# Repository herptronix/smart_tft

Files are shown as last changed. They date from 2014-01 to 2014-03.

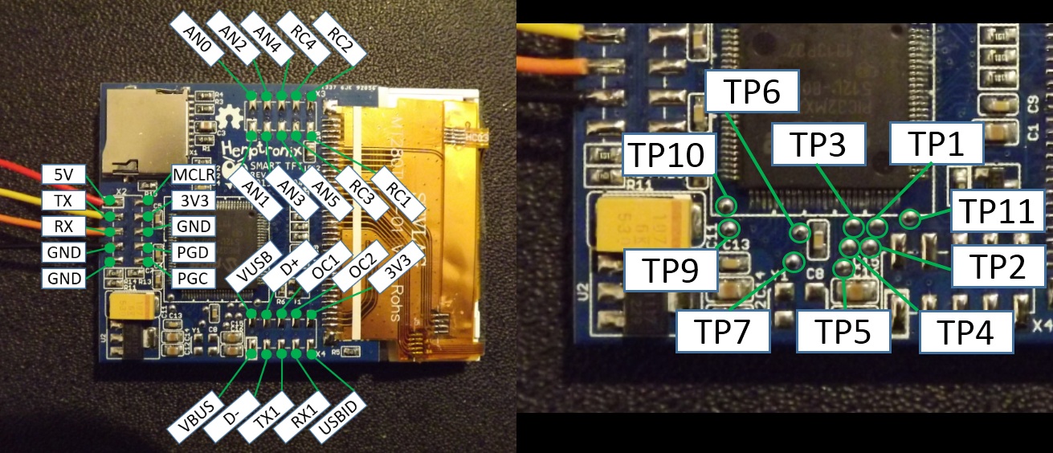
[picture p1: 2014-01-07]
documentation/pin_description.jpg

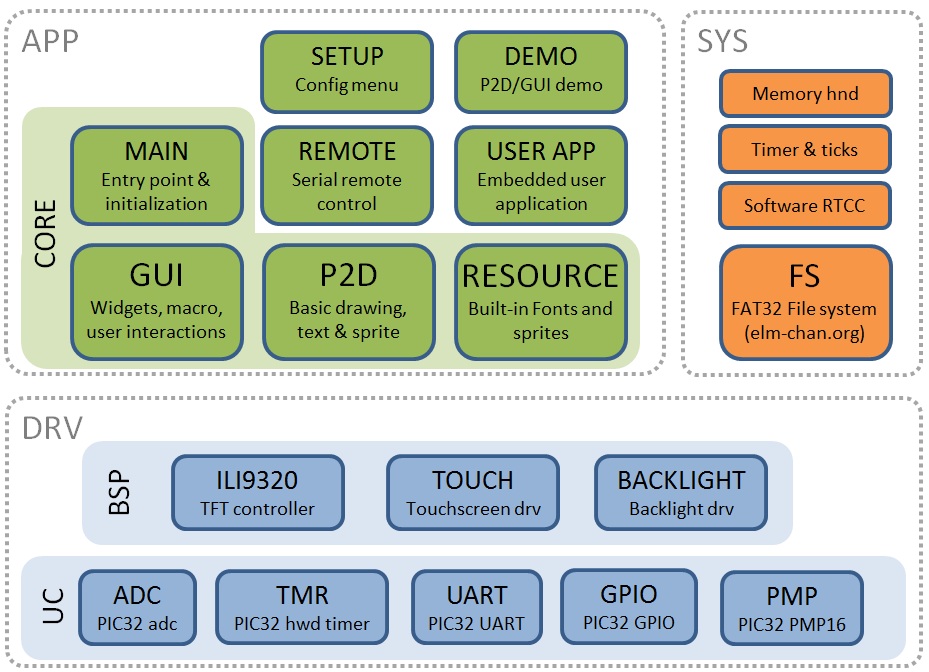
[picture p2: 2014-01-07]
documentation/software_arch.jpg

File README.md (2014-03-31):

Smart TFT module
================

Open source (hardware & software) smart TFT module, based on:
 - Microchip PIC32MX795F512L microcontroller
 - 3.2" TFT 320x240, ILI9320/9325 controller
 - optional µSD card, for extra storage

This module has three operational modes:
 - slave: an other microcontroller sends commands to the TFT through UART (1M bauds, 8N1)
 - embedded app: the user includes its application directly into the PIC32
 - setup: setup menu, for touchscreen callibration, gamma adjustement & software demo; enter this mode by keeping the touchscreen pressed while powering on the 5V PSU.

Small video: https://www.youtube.com/watch?v=Nt97tPhJtdA
Some explanations (french only): http://herptronix.blogspot.fr/

## Pins & wirepads description ##
pin_desription

## Software modules ##
software_arch

## Screenshots ##
screenshots

## Pickit3 ##
pickit

Status
======

Maintained

 - 2014/03/31 Add sprite & font converters (sources & win32 exe)
 - 2014/02/27 Add display orientation support (limited to BSP) & Minor bug fixes
 - 2014/02/01 Minor bug fixes (p2d_font.c / touchCalib.c / gui_w_usr_entry.c)
 - 2014/01/15 Add a quick & dirty (... and not yet completed) dev. guide
 - 2014/01/09 Add a serial remote example
 - 2013/12/29 Rev. A (improved P2D/GUI, FAT-FS support, setup menu, serial comm support)
 - 2013/08/11 First GUI version (not on git)
 - 2013/07/13 First P2D version (not on git)

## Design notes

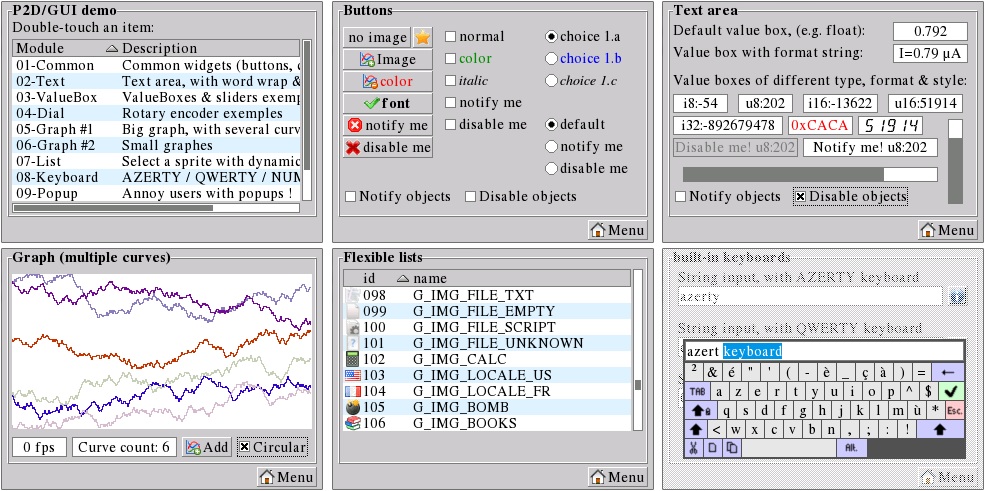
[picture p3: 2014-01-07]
documentation/screenshots.jpg

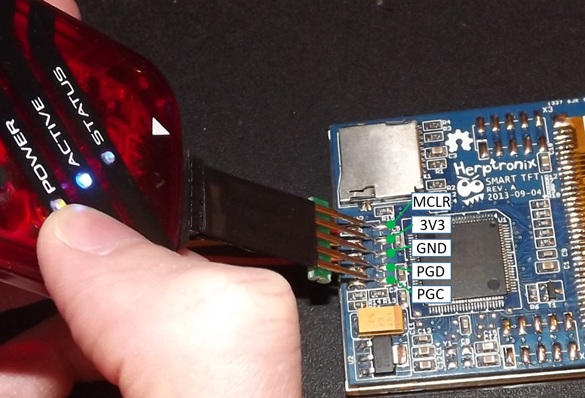
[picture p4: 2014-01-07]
documentation/pickit.jpg

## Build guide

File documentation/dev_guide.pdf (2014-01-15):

Herptronix

Smart display dev. guide

DRAFT / UNCOMPLETE

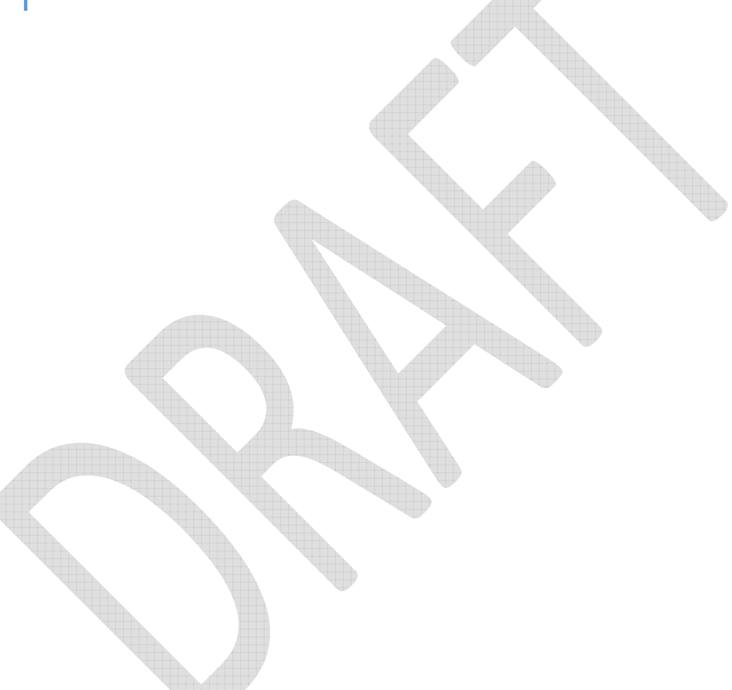
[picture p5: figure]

Developer Guide | 1 / 68

### 1. Summary

Developer Guide | 2 / 68

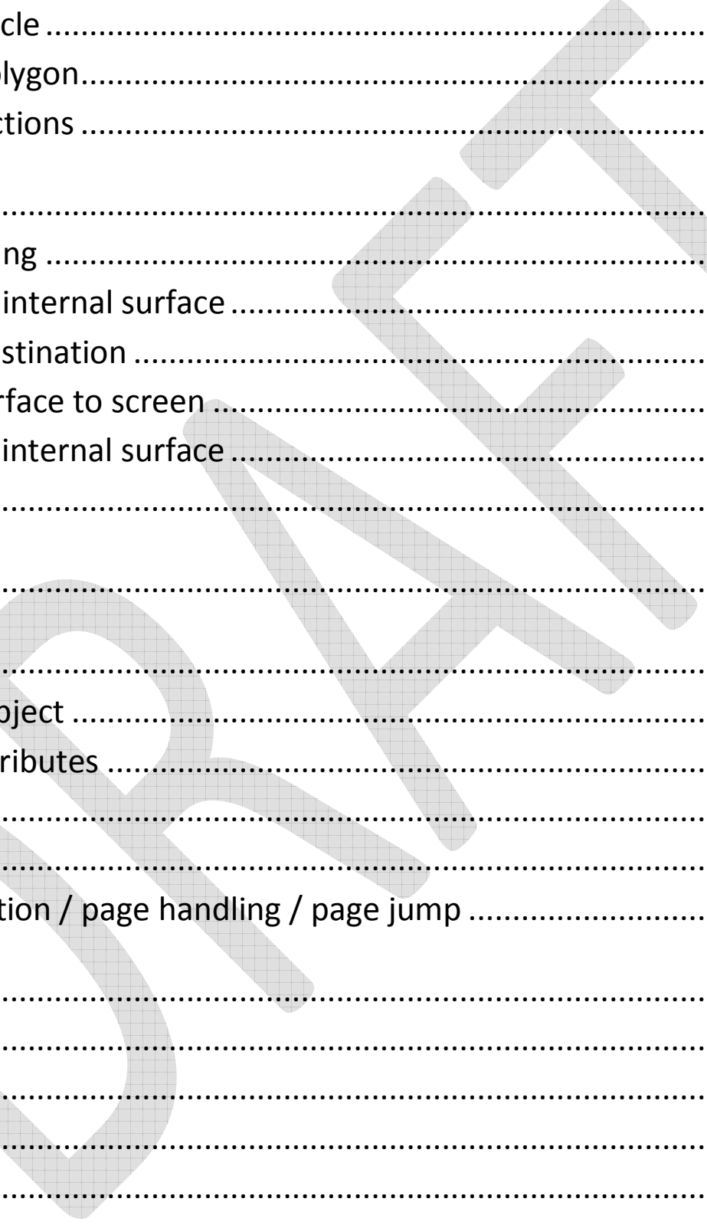
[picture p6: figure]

Developer Guide | 3 / 68

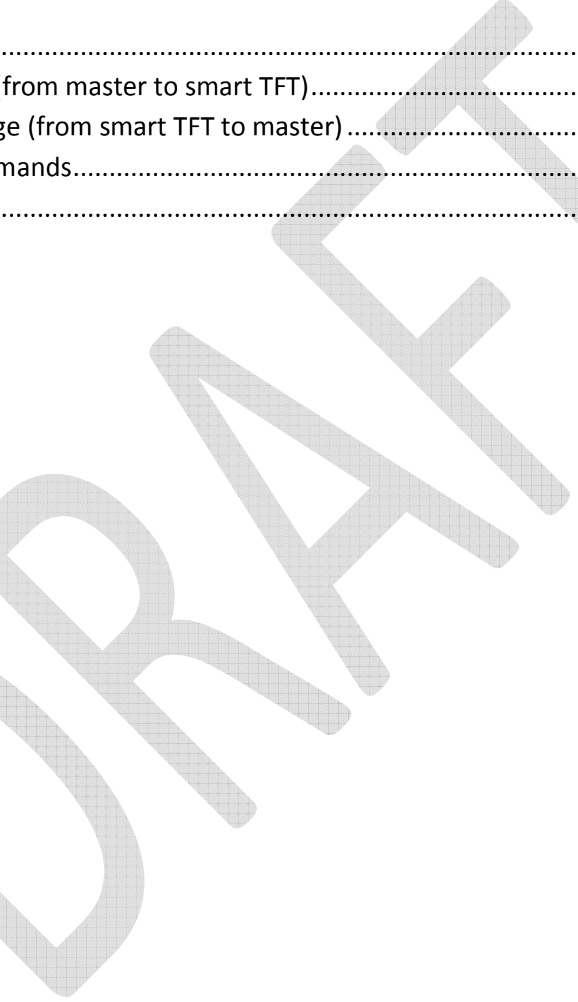
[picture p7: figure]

Developer Guide | 4 / 68

### 2. Licensing

Software of this project is under GPL3 license:

This program is free software: you can redistribute it and/or modify it under the terms of the GNU General Public License as published by the Free Software Foundation, either version 3 of the License, or (at your option) any later version.

This program is distributed in the hope that it will be useful, but WITHOUT ANY WARRANTY; without even the implied warranty of MERCHANTABILITY or FITNESS FOR A PARTICULAR PURPOSE. See the GNU General Public License for more details.

You should have received a copy of the GNU General Public License along with this program. If not, see

http://www.gnu.org/licenses/.

### 3. Overview

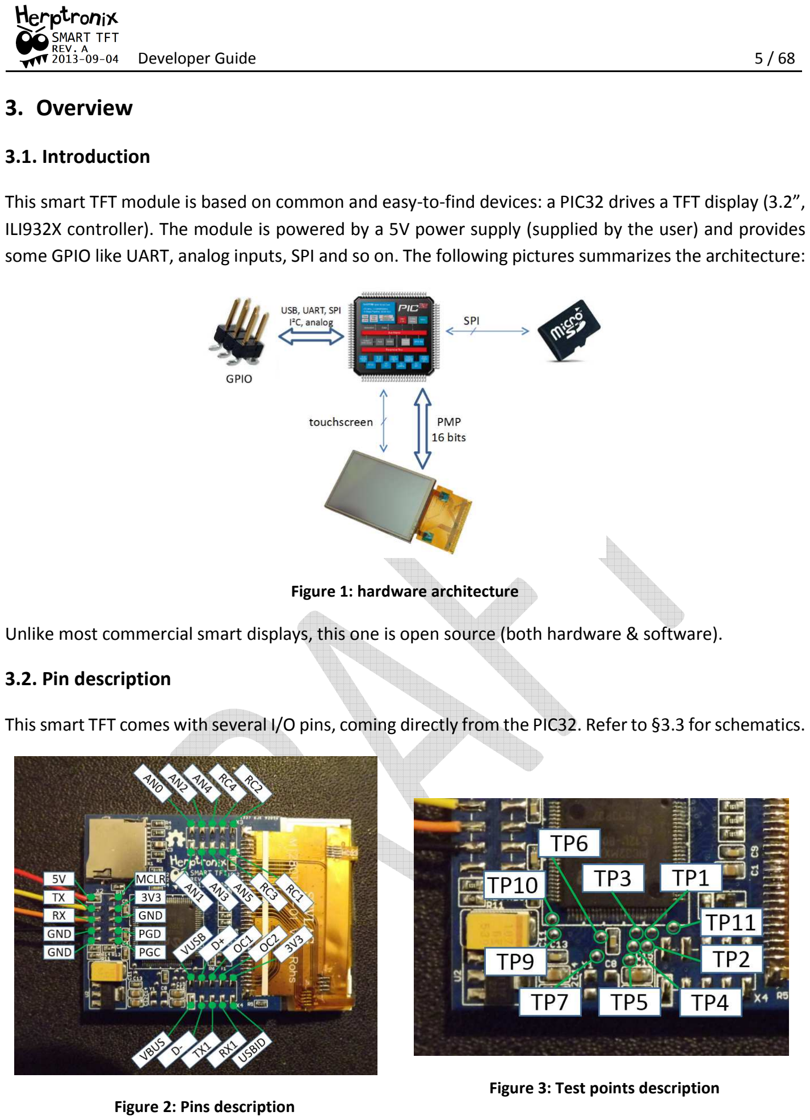
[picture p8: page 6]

Developer Guide | 5 / 68

### 3.1. Introduction

This smart TFT module is based on common and easy-to-find devices: a PIC32 drives a TFT display (3.2”, ILI932X controller). The module is powered by a 5V power supply (supplied by the user) and provides some GPIO like UART, analog inputs, SPI and so on. The following pictures summarizes the architecture:

Figure 1: hardware architecture

Unlike most commercial smart displays, this one is open source (both hardware & software).

### 3.2. Pin description

This smart TFT comes with several I/O pins, coming directly from the PIC32. Refer to §3.3 for schematics.

Figure 2: Pins description

Figure 3: Test points description

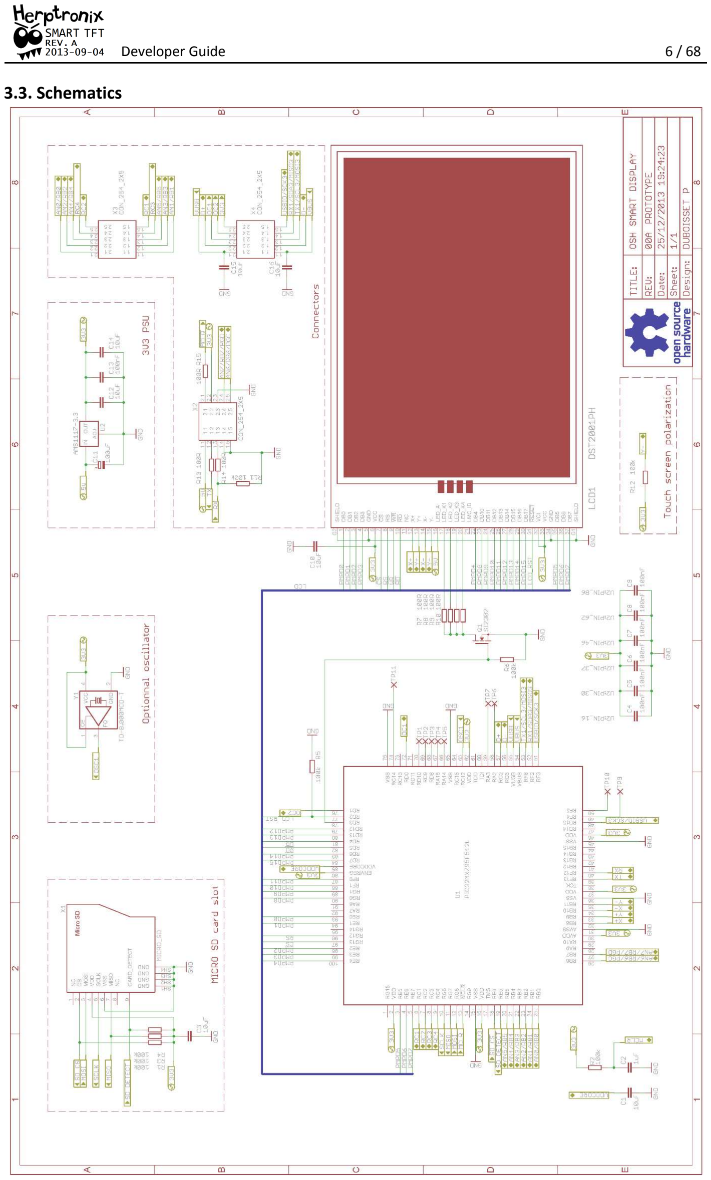
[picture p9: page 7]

Developer Guide | 6 / 68

### 3.3. Schematics

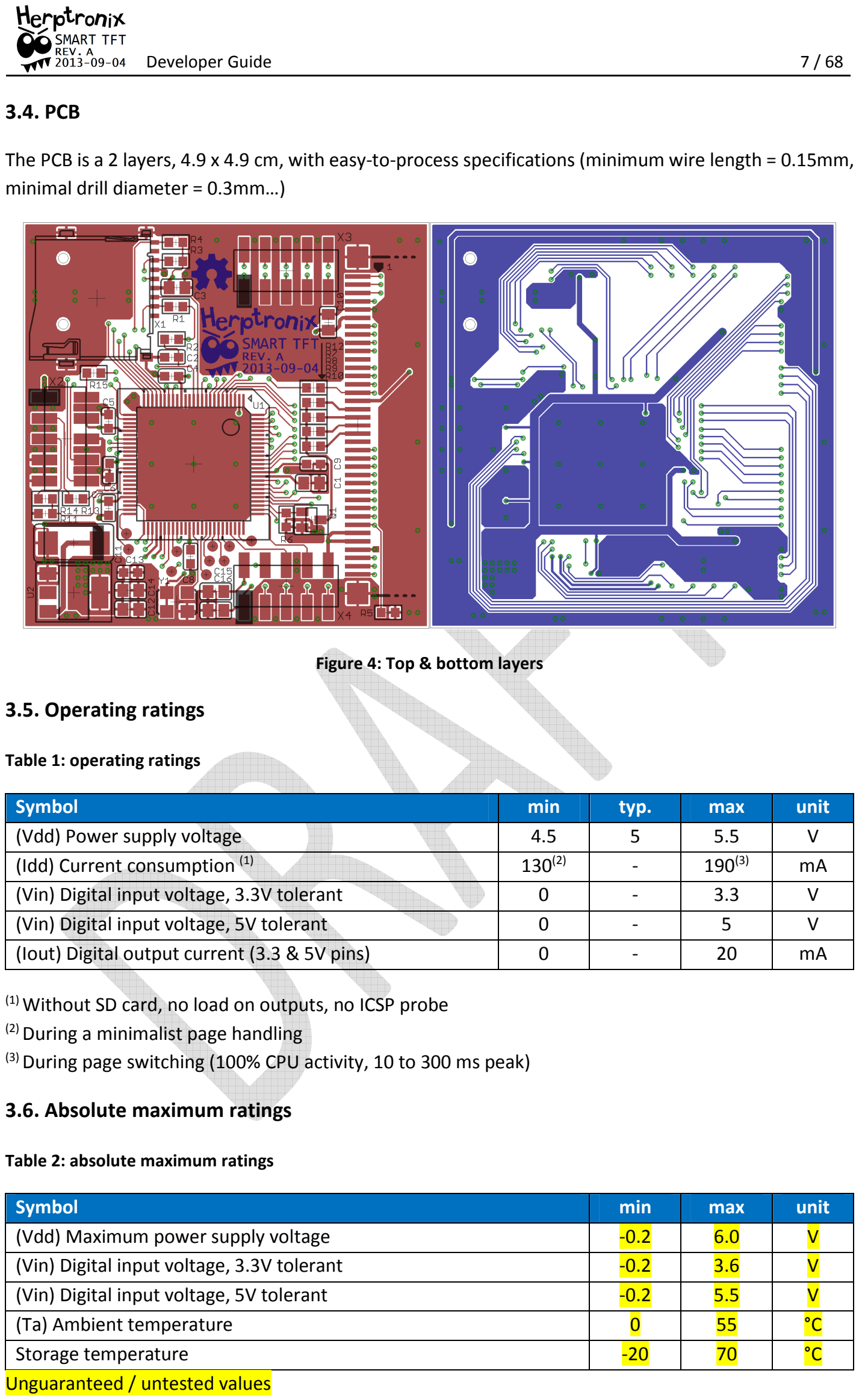
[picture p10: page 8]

Developer Guide | 7 / 68

### 3.4. PCB

The PCB is a 2 layers, 4.9 x 4.9 cm, with easy-to-process specifications (minimum wire length = 0.15mm, minimal drill diameter = 0.3mm…)

Figure 4: Top & bottom layers

### 3.5. Operating ratings

Table 1: operating ratings

Symbol | min | typ. | max | unit
(Vdd) Power supply voltage | 4.5 | 5 | 5.5 | V
(Idd) Current consumption ⁽¹⁾ | 130 (2) | - | 190⁽³⁾ | mA
(Vin) Digital input voltage, 3.3V tolerant | 0 | - | 3.3 | V
(Vin) Digital input voltage, 5V tolerant | 0 | - | 5 | V
(Iout) Digital output current (3.3 & 5V pins) | 0 | - | 20 | mA
(1) Without SD card, no load on outputs, no ICSP probe
(2) During a minimalist page handling
(3) During page switching (100% CPU activity, 10 to 300 ms peak)

### 3.6. Absolute maximum ratings

Table 2: absolute maximum ratings

Symbol | min | max | unit
(Vdd) Maximum power supply voltage | -0.2 | 6.0 | V
(Vin) Digital input voltage, 3.3V tolerant | -0.2 | 3.6 | V
(Vin) Digital input voltage, 5V tolerant | -0.2 | 5.5 | V
(Ta) Ambient temperature | 0 | 55 | °C
Storage temperature | -20 | 70 | °C
Unguaranteed / untested values

Developer Guide | 8 / 68

### 3.7. Mode of operation

This smart TFT has 2 different operational modes, selected at compilation time:
- Slave mode
- Embedded application mode
Another mode (setup mode) is always included, which provides a software demonstration, touchscreen configuration and gamma adjustment.

### 3.7.1. Slave (default)

In slave mode (which is the default mode), the smart TFT executes commands sent by a master (e.g. another MCU) through the UART. The firmware of the smart TFT does not require any modification, but the master shall integrate some additional source files for driving it. These source files are provided as an example, and should be re-written in a more efficient way.

For using the slave mode, the smart TFT shall be wired to a remote system through 4 wires:

- 5VIN: 5V power supply (see Table 1: operating ratings for current consumption)
- GND: power supply ground
- TX: Transmitted data (from the smart TFT to the master). This pin shall be connected to the RX of the master
- RX: Received data (from the master to the smart TFT). This pin shall be connected to the TX of the master

Default configuration is set to 1M bauds, 8N1. UART speed can be changed by modifying the UART_SPEED definition in <src/app/serial_remote/serial_common.h> file.

### 3.7.2. Embedded application

In this mode, the user application is integrated into the firmware of the smart TFT; user will have to modify the source code and upload its custom firmware into the smart TFT with an ICSP probe (e.g. a PICKIT 3). Paragraphs below describe a typical procedure for enabling this mode.

The smart TFT does not include a bootloader yet. An ICSP probe is required to upgrade the firmware

3.7.2.1.Get the MPLAB X project

The distributed MPLAB X project has been released using the following tools:
- MPLAB X version 1.90
- C32 compiler version 2.02, using –O3 optimizations (if you do not have the license, the free version provides these optimizations during 60 days). Compilation with another compiler (e.g. XC32) has not been tested.

3.7.2.2.Configure the ICSP probe

Just ensure that the ICSP probe is powered by the smart TFT (here, a PICKIT3 cannot power the smart TFT; it would damage it):

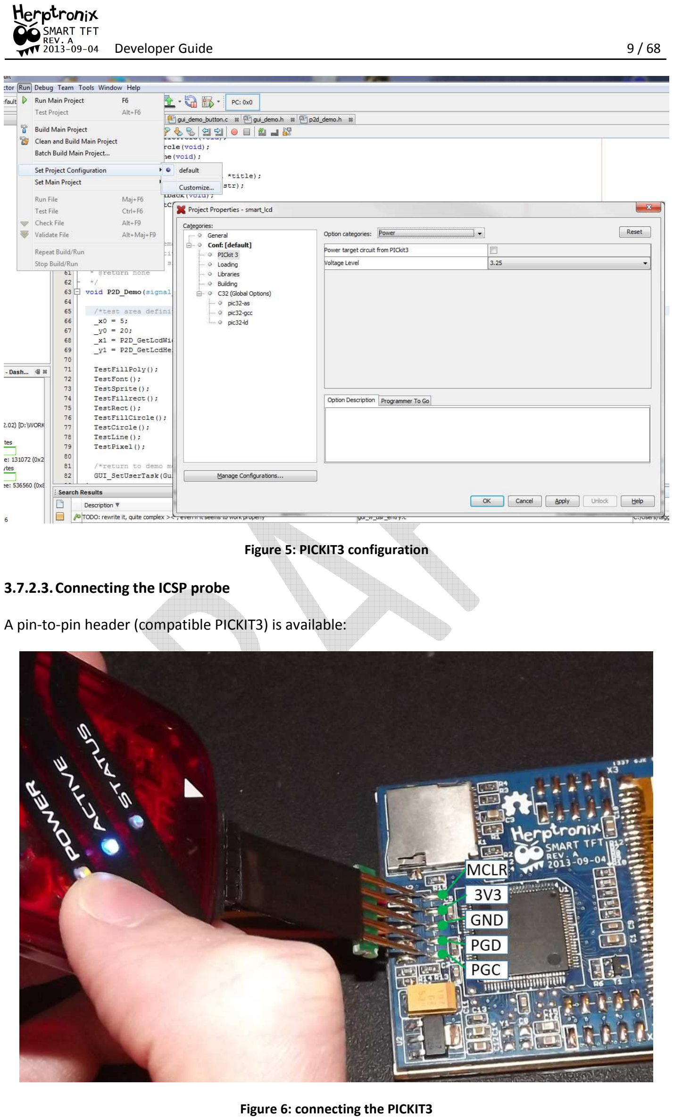
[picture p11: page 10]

Developer Guide | 9 / 68

Figure 5: PICKIT3 configuration

3.7.2.3.Connecting the ICSP probe

A pin-to-pin header (compatible PICKIT3) is available:

Figure 6: connecting the PICKIT3

Developer Guide | 10 / 68

3.7.2.4.Define the embedded app mode

Open the <src/main.h> header and comment the SMART_TFT_SLAVE_MODE symbol:

3.7.2.5.Include your app

You can add your program in the UserTask() function, located in <src/app/usr/usr_main.c> file. The firmware of the smart TFT will call this function at each software cycle.
A basic embedded application is included in source code (comes as an example).

Due to the absence of RTOS, the embedded application shall manually yield the CPU (i.e. do not use infinite loop).

### 3.7.3. Setup

This mode allows configuring the touchscreen and running a demonstration. This mode is launched following the steps below:
- With the smart TFT powered OFF, press the touch screen
- By keeping the touch screen pressed, power ON the smart TFT
The setup screen appears:

After 3 seconds of inactivity from the touchscreen, the smart TFT will enter the highlighted item.

3.7.3.1.Touchscreen calibration

Touchscreen calibration is based on a 2 points algorithm

Parameters for touchscreen calibration are stored on the µSD card (/TOUCHSCR.CFG file); if the µSD card is not inserted, touchscreen will be calibrated with internal default parameters (i.e. without the TOUCHSCR.CFG file, the touchscreen may be “reversed”).

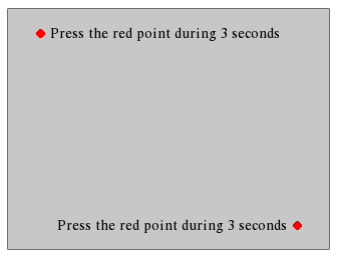
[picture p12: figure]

Developer Guide | 11 / 68

3.7.3.2.Gamma adjustment

Parameters for gamma adjustment are stored on the µSD card (/GAMMA.CFG file); if the µSD card is not inserted, gamma will be calibrated with internal default parameters

Report to the TFT controller documentation for the description of gamma registers

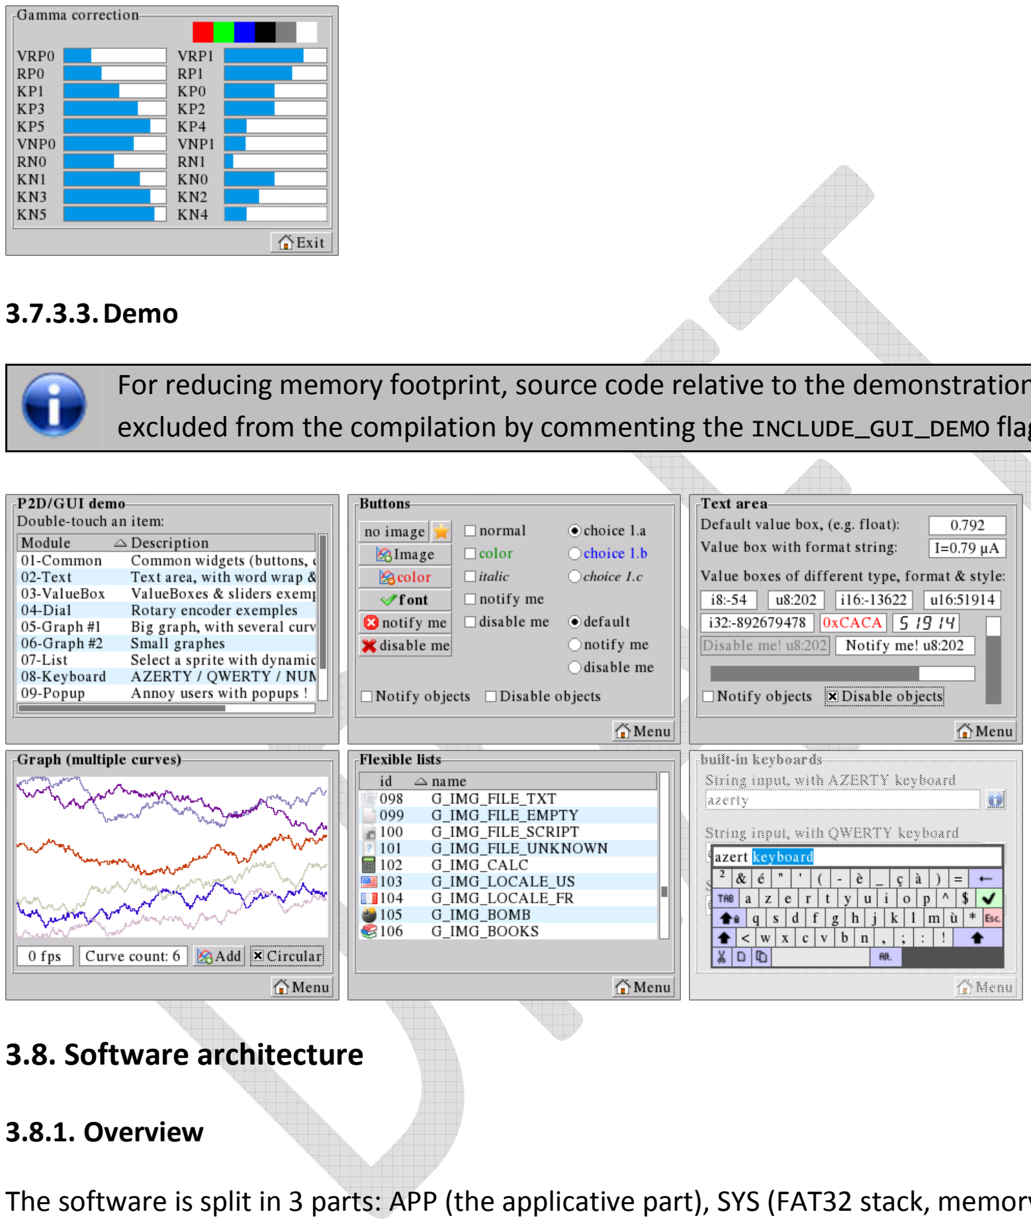
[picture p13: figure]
3.7.3.3.Demo; 3.8. Software architecture; 3.8.1. Overview

For reducing memory footprint, source code relative to the demonstration can be easily excluded from the compilation by commenting the INCLUDE_GUI_DEMO flag in <main.h>

The software is split in 3 parts: APP (the applicative part), SYS (FAT32 stack, memory allocator, etc…) and DRV (peripherals & microcontroller drivers).

The Figure 7: software architecture describes the software architecture:

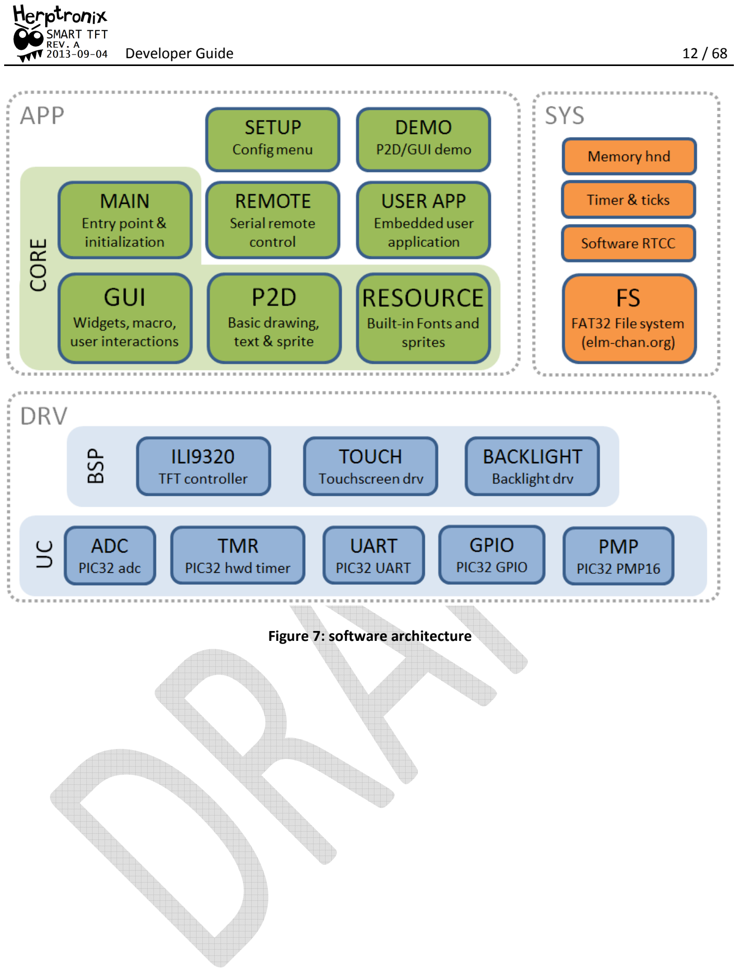
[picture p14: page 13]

Developer Guide | 12 / 68

Figure 7: software architecture

Developer Guide | 13 / 68

### 3.8.2. Files description

The table above lists source code files constituting this project.

Table 3: Files description

File (.c) | Description
main | The main function; includes initialization and main loop
app\gui\macro\file_browser\gui_m_file_browser | Built-in file browser (µSD file browser)
app\gui\macro\keyboard\ gui_m_keyboard | Built-in keyboard (AZERTY / QWERTY & NUM, with insert / copy-paste features)
app\gui\macro\keyboard\ gui_w_key | Small widget for the built-in keyboard
app\gui\macro\keyboard\ keymap | Keyboards mappings (describes keys for AZERTY / QWERTY & NUM configuration)
app\gui\macro\list\ gui_m_list | Lists builder; create flexible lists, the easy way.
app\gui\macro\popup\ gui_m_popup | Built-in popups
app\gui\widgets\gui_w_button | Standard buttons
app\gui\widgets\gui_w_checkBox | Standard check boxes
app\gui\widgets\gui_w_frame | Frames (a text plus a rectangle)
app\gui\widgets\gui_w_graph | Graphs (normal & scrolled)
app\gui\widgets\gui_w_led | LED (red or green, according to their relative status)
app\gui\widgets\gui_w_list | Flexible lists implementation; use functions provided by gui_m_list
app\gui\widgets\gui_w_radio | Standard radios
app\gui\widgets\gui_w_rot_button | Rotary encoder
app\gui\widgets\gui_w_rot_value | Special value box, for rotary encoder
app\gui\widgets\gui_w_scroller | Standard scroll bar
app\gui\widgets\gui_w_slider | Standard slider
app\gui\widgets\gui_w_tab | Tabs (deprecated)
app\gui\widgets\gui_w_text | Text area (supports alignment & line feed)
app\gui\widgets\gui_w_usr_entry | User entry bar; allow string edition
app\gui\widgets\gui_w_valueBox | Value boxes; display formatted values

Developer Guide | 14 / 68
app\gui\gui_debug | GUI debug utils (memory usage)
app\gui\gui_graphics | GUI graphic wrapper; handle fonts & sprites through #id
app\gui\gui_obj | GUI generic object implementation + GUI task
app\gui\gui_utils | GUI utility
app\gui_demo\gui_demo | Main menu of GUI demo
app\gui_demo\gui_demo_button | generic widgets demo (buttons, radios, checkboxes)
app\gui_demo\gui_demo_file_browser | file browser demo
app\gui_demo\gui_demo_graph1 | graph demo #1 (big graph with multiple curves)
app\gui_demo\gui_demo_graph2 | graph demo #2 (small graphs & grid)
app\gui_demo\gui_demo_keyboard | keyboard demo
app\gui_demo\gui_demo_list | flexible lists demo
app\gui_demo\gui_demo_popup | popup demo
app\gui_demo\gui_demo_rbutton | rotary encoder demo
app\gui_demo\gui_demo_sd | SD card example
app\gui_demo\gui_demo_text | text area demo
app\gui_demo\gui_demo_valuebox | value boxes demo
app\p2d\p2d_base | Basic 2D functions (pixel, rectangle, …)
app\p2d\p2d_buffer | Memory buffer (deprecated)
app\p2d\p2d_clip | Clipping
app\p2d\p2d_colors | Color conversion (RGB888 <-> RGB565, alpha, B&W…)
app\p2d\p2d_font | Text rendering
app\p2d\p2d_geo_circle | Circle & filled circle
app\p2d\p2d_geo_line | Lines
app\p2d\p2d_geo_poly | Polygon & filled polygon, plus polygon-oriented functions
app\p2d\p2d_internal | Functions dispatching (to TFT or to memory)
app\p2d\p2d_lut | Color look-up tables
app\p2d\p2d_math | Some math functions
app\p2d\p2d_sprite | Sprite rendering (only 8BPP)

Developer Guide | 15 / 68
app\p2d\p2d_utils | Some utils (distance calculation, etc…)
app\resources\FontDigit_4bpp | Font digit (7 segments style)
app\resources\FontSerif_4bpp_b | Font free serif, bold; comes with many heights.
app\resources\FontSerif_4bpp_i | Font free serif, italic; comes with many heights.
app\resources\FontSerif_4bpp_n | Font free serif, normal; comes with many heights.
app\resources\FontSymbol | Some symbol used by the built-in keyboard
app\resources\sprite00 | Sprite pack #00 (16x16)
app\resources\sprite01 | Sprite pack #01 (16x16)
app\resources\sprite02 | Sprite pack #02 (16x16)
app\resources\sprite03 | Sprite pack #03 (16x16)
app\resources\sprite04 | Sprite pack #04 (32x32)
app\serial_remote\opList | List of operators (~ link with P2D/GUI) handled by the serial remote
app\serial_remote\r_gui | GUI serialized functions
app\serial_remote\r_mem | Memory serialized functions
app\serial_remote\r_p2d | P2D serialized functions
app\serial_remote\serial_remote | Serial remote task & FSM
app\serial_remote\serial_rx | Functions for message reception
app\serial_remote\serial_tx | Functions for message emission
app\serial_remote\ssm | Serialized shared memory
app\setup\gamma | Gamma adjustment
app\setup\setup | Setup menu
app\setup\touchCalib | Touchscreen calibration
app\user_app\usr_main | User application (disabled by default)
drv\bsp\backlight | Backlight driver (dummy for now)
drv\bsp\ILI9320 | TFT controller driver
drv\bsp\touchscreen | Touchscreen driver
drv\uc\adc | PIC32 ADC driver
drv\uc\configuration_bits | PIC32 fuses

Developer Guide | 16 / 68
drv\uc\gpio | PIC32 GPIO driver
drv\uc\hw_config | Hardware constants (e.g. clock frequency)
drv\uc\pmp | PIC32 parallel master port driver (16 bits mode)
drv\uc\sem | Atomic write macro (quick & dirty spinlock for interrupts)
drv\uc\tmr | PIC32 timers driver
drv\uc\uart | PIC32 UART driver
drv\uc\uc | PIC32 core utils (e.g. sleep mode)
sys\file_system\diskio | FAT-FS part (see http://elm-chan.org/fsw/ff/00index_e.html)
sys\file_system\ff | FAT-FS part (see http://elm-chan.org/fsw/ff/00index_e.html)
sys\file_system\ffconf | FAT-FS part (see http://elm-chan.org/fsw/ff/00index_e.html)
sys\file_system\integer | FAT-FS part (see http://elm-chan.org/fsw/ff/00index_e.html)
sys\file_system\mmcPIC32 | PIC32 specific for FAT-FS
sys\delay | Delay functions
sys\rtc | Software RTCC (needed by FAT-FS)
sys\salloc | Custom memory allocator (used by GUI)
sys\ticks | Software clock
sys\timer | Software timers

Developer Guide | 17 / 68

### 4. Built-in resources

The firmware includes some built-in graphical resources (images and fonts). These resources are listed in the tables below.

### 4.1. Images

The tables below list built-in images and their available CLUTs. Built-in images come from the open icon library project (http://openiconlibrary.sourceforge.net/)

Due to bandwidth limitations, P2D & GUI do not handle images which are located on the micro SD card.

Table 4: available CLUTs

CLUT symbol | Description
G_LUT_NORMAL | This CLUT is the ‘default’ one; by using this CLUT, the image will be displayed as it appears in Table 5 & Table 6
G_LUT_DISABLED | By using this CLUT, the image will be displayed in black & white; due to memory limitations, this CLUT is not available for all images.

Table 5: built-in 16x16 images

defined symbol (see src/app/resources.h) | Available CLUTs
G_IMG_OK | G_LUT_NORMAL, G_LUT_DISABLED
G_IMG_NO | G_LUT_NORMAL, G_LUT_DISABLED
G_IMG_ADD | G_LUT_NORMAL, G_LUT_DISABLED
G_IMG_REMOVE | G_LUT_NORMAL, G_LUT_DISABLED
G_IMG_LEFT_ARROW | G_LUT_NORMAL, G_LUT_DISABLED
G_IMG_LEFT_D_ARROW | G_LUT_NORMAL, G_LUT_DISABLED
G_IMG_DOWN_ARROW | G_LUT_NORMAL, G_LUT_DISABLED
G_IMG_DOWN_D_ARROW | G_LUT_NORMAL, G_LUT_DISABLED
G_IMG_RIGHT_ARROW | G_LUT_NORMAL, G_LUT_DISABLED
G_IMG_RIGHT_D_ARROW | G_LUT_NORMAL, G_LUT_DISABLED
G_IMG_UP_ARROW | G_LUT_NORMAL, G_LUT_DISABLED
G_IMG_UP_D_ARROW | G_LUT_NORMAL, G_LUT_DISABLED
G_IMG_GO_LEFT | G_LUT_NORMAL, G_LUT_DISABLED
G_IMG_GO_DOWN | G_LUT_NORMAL, G_LUT_DISABLED
G_IMG_GO_RIGHT | G_LUT_NORMAL, G_LUT_DISABLED
G_IMG_GO_UP | G_LUT_NORMAL, G_LUT_DISABLED
G_IMG_CONFIG | G_LUT_NORMAL, G_LUT_DISABLED
G_IMG_FORBID | G_LUT_NORMAL, G_LUT_DISABLED
G_IMG_ERROR | G_LUT_NORMAL, G_LUT_DISABLED
G_IMG_SAVE | G_LUT_NORMAL, G_LUT_DISABLED
G_IMG_OPEN | G_LUT_NORMAL, G_LUT_DISABLED
G_IMG_EDIT | G_LUT_NORMAL, G_LUT_DISABLED

Developer Guide | 18 / 68
G_IMG_INFO | G_LUT_NORMAL, G_LUT_DISABLED
G_IMG_HELP | G_LUT_NORMAL, G_LUT_DISABLED
G_IMG_HOME | G_LUT_NORMAL, G_LUT_DISABLED
G_IMG_REFRESH | G_LUT_NORMAL, G_LUT_DISABLED
G_IMG_IMPORTANT | G_LUT_NORMAL, G_LUT_DISABLED
G_IMG_EXIT | G_LUT_NORMAL, G_LUT_DISABLED
G_IMG_EJECT | G_LUT_NORMAL, G_LUT_DISABLED
G_IMG_PAUSE | G_LUT_NORMAL, G_LUT_DISABLED
G_IMG_STOP | G_LUT_NORMAL, G_LUT_DISABLED
G_IMG_REC | G_LUT_NORMAL, G_LUT_DISABLED
G_IMG_FIND | G_LUT_NORMAL, G_LUT_DISABLED
G_IMG_ZOOM_1 | G_LUT_NORMAL, G_LUT_DISABLED
G_IMG_ZOOM_OUT | G_LUT_NORMAL, G_LUT_DISABLED
G_IMG_ZOOM_IN | G_LUT_NORMAL, G_LUT_DISABLED
G_IMG_ACCEPT | G_LUT_NORMAL, G_LUT_DISABLED
G_IMG_DECLINE | G_LUT_NORMAL, G_LUT_DISABLED
G_IMG_SORT_DOWN | G_LUT_NORMAL, G_LUT_DISABLED
G_IMG_SORT_UP | G_LUT_NORMAL, G_LUT_DISABLED
G_IMG_BOOKMARK | G_LUT_NORMAL, G_LUT_DISABLED
G_IMG_GRAPH_ADD | G_LUT_NORMAL, G_LUT_DISABLED
G_IMG_GRAPH_REMOVE | G_LUT_NORMAL, G_LUT_DISABLED
G_IMG_GRAPH_EDIT | G_LUT_NORMAL, G_LUT_DISABLED
G_IMG_DOWNLOAD | G_LUT_NORMAL, G_LUT_DISABLED
G_IMG_CLEAR | G_LUT_NORMAL, G_LUT_DISABLED
G_IMG_CUT | G_LUT_NORMAL, G_LUT_DISABLED
G_IMG_DRAG | G_LUT_NORMAL, G_LUT_DISABLED
G_IMG_SMILE | G_LUT_NORMAL, G_LUT_DISABLED
G_IMG_HISTOGRAM | G_LUT_NORMAL, G_LUT_DISABLED
G_IMG_LOCK | G_LUT_NORMAL, G_LUT_DISABLED
G_IMG_BULB | G_LUT_NORMAL, G_LUT_DISABLED
G_IMG_OSCILLOSCOPE | G_LUT_NORMAL, G_LUT_DISABLED
G_IMG_TASK | G_LUT_NORMAL, G_LUT_DISABLED
G_IMG_WARNING | G_LUT_NORMAL, G_LUT_DISABLED
G_IMG_DEVICE | G_LUT_NORMAL
G_IMG_SND_MUTE | G_LUT_NORMAL
G_IMG_SOUND_MIN | G_LUT_NORMAL
G_IMG_SOUND_MEDIUM | G_LUT_NORMAL
G_IMG_SOUND_MAX | G_LUT_NORMAL
G_IMG_BATTERY_MIN | G_LUT_NORMAL
G_IMG_BATTERY_MEDIUM | G_LUT_NORMAL
G_IMG_BATTERY_GOOD | G_LUT_NORMAL
G_IMG_BATTERY_MAX | G_LUT_NORMAL
G_IMG_BATTERY_C_MIN | G_LUT_NORMAL
G_IMG_BATTERY_C_MEDIUM | G_LUT_NORMAL
G_IMG_BATTERY_C_GOOD | G_LUT_NORMAL

Developer Guide | 19 / 68
G_IMG_BATTERY_C_MAX | G_LUT_NORMAL
G_IMG_COMPUTER | G_LUT_NORMAL
G_IMG_SD_CARD | G_LUT_NORMAL
G_IMG_SIGNAL_NONE | G_LUT_NORMAL
G_IMG_SIGNAL_MIN | G_LUT_NORMAL
G_IMG_SIGNAL_MEDIUM | G_LUT_NORMAL
G_IMG_SIGNAL_GOOD | G_LUT_NORMAL
G_IMG_SIGNAL_MAX | G_LUT_NORMAL
G_IMG_SAFE | G_LUT_NORMAL
G_IMG_UNSAFE | G_LUT_NORMAL
G_IMG_USB | G_LUT_NORMAL
G_IMG_CLOCK | G_LUT_NORMAL
G_IMG_FILE_INFO | G_LUT_NORMAL
G_IMG_FILE_APP | G_LUT_NORMAL
G_IMG_FILE_APP_WIN | G_LUT_NORMAL
G_IMG_FILE_ZIP | G_LUT_NORMAL
G_IMG_FILE_AUDIO | G_LUT_NORMAL
G_IMG_FILE_PACK | G_LUT_NORMAL
G_IMG_FILE_ENCRYPTED | G_LUT_NORMAL
G_IMG_FILE_IMPORTANT | G_LUT_NORMAL
G_IMG_FILE_TMP | G_LUT_NORMAL
G_IMG_FOLDER | G_LUT_NORMAL
G_IMG_FILE_FONT | G_LUT_NORMAL
G_IMG_FILE_IMGS | G_LUT_NORMAL
G_IMG_FILE_IMG | G_LUT_NORMAL
G_IMG_FILE_PACK2 | G_LUT_NORMAL
G_IMG_FILE_HTML | G_LUT_NORMAL
G_IMG_FILE_ASM | G_LUT_NORMAL
G_IMG_FILE_H | G_LUT_NORMAL
G_IMG_FILE_C | G_LUT_NORMAL
G_IMG_FILE_TXT | G_LUT_NORMAL
G_IMG_FILE_EMPTY | G_LUT_NORMAL
G_IMG_FILE_SCRIPT | G_LUT_NORMAL
G_IMG_FILE_UNKNOWN | G_LUT_NORMAL
G_IMG_CALC | G_LUT_NORMAL
G_IMG_LOCALE_US | G_LUT_NORMAL
G_IMG_LOCALE_FR | G_LUT_NORMAL
G_IMG_BOMB | G_LUT_NORMAL
G_IMG_BOOKS | G_LUT_NORMAL
G_IMG_PACKAGE | G_LUT_NORMAL
G_IMG_BRICKS | G_LUT_NORMAL
G_IMG_CART | G_LUT_NORMAL
G_IMG_CREDIT_CARDS | G_LUT_NORMAL
G_IMG_DB_ERROR | G_LUT_NORMAL
G_IMG_EYE | G_LUT_NORMAL

Developer Guide | 20 / 68
G_IMG_FLAG_BLUE | G_LUT_NORMAL
G_IMG_FLAG_GREEN | G_LUT_NORMAL
G_IMG_FLAG_ORANGE | G_LUT_NORMAL
G_IMG_FLAG_PINK | G_LUT_NORMAL
G_IMG_FLAG_PURPLE | G_LUT_NORMAL
G_IMG_FLAG_RED | G_LUT_NORMAL
G_IMG_FLAG_YELLOW | G_LUT_NORMAL
G_IMG_PICTURES | G_LUT_NORMAL
G_IMG_WINDOWS | G_LUT_NORMAL
G_IMG_MONEY | G_LUT_NORMAL
G_IMG_MUSIC | G_LUT_NORMAL
G_IMG_SHEETS | G_LUT_NORMAL
G_IMG_PACKAGE2 | G_LUT_NORMAL
G_IMG_ROSETTE | G_LUT_NORMAL
G_IMG_TAG_BLUE | G_LUT_NORMAL
G_IMG_TAG_GREEN | G_LUT_NORMAL
G_IMG_TAG_ORANGE | G_LUT_NORMAL
G_IMG_TAG_PINK | G_LUT_NORMAL
G_IMG_TAG_PURPLE | G_LUT_NORMAL
G_IMG_TAG_RED | G_LUT_NORMAL
G_IMG_TAG_YELLOW | G_LUT_NORMAL
G_IMG_TUX | G_LUT_NORMAL
G_IMG_USER_BLUE | G_LUT_NORMAL
G_IMG_USER_PURPLE | G_LUT_NORMAL
G_IMG_USER_GREY | G_LUT_NORMAL
G_IMG_USER_GREEN | G_LUT_NORMAL
G_IMG_USER_ORANGE | G_LUT_NORMAL
G_IMG_USER_RED | G_LUT_NORMAL
G_IMG_USER_BLUE2 | G_LUT_NORMAL

Table 6: built-in 32x32 images

defined symbol | Available CLUTs
G_IMG_BIG_ERROR | G_LUT_NORMAL
G_IMG_BIG_OK | G_LUT_NORMAL
G_IMG_BIG_WARNING | G_LUT_NORMAL
G_IMG_BIG_INFO | G_LUT_NORMAL
G_IMG_BIG_ASK | G_LUT_NORMAL
G_IMG_BIG_SAVED | G_LUT_NORMAL
G_IMG_BIG_SD_CARD | G_LUT_NORMAL

Developer Guide | 21 / 68
G_IMG_BIG_BATTERY_EMPTY | G_LUT_NORMAL
G_IMG_BIG_NO_SIGNAL | G_LUT_NORMAL

### 4.2. Font

The tables below list built-in fonts and their available glyphs.

Due to bandwidth limitations, P2D & GUI do not handle fonts which are located on the micro SD card.

Non-ASCII glyphs (Chinese, Cyrillic, Korean…) are not supported

Table 7: built-in fonts (default)

Render (in a 320x240 surface) | defined symbol | glyph min | glyph max
| G_FONT_DEFAULT | 32 | 255
| G_FONT_BOLD | 32 | 255
| G_FONT_ITALIC | 32 | 255
| G_FONT_DIGIT | 42 | 63
| G_FONT_BIG | 32 | 255

Developer Guide | 22 / 68
| G_FONT_VERY_BIG | 32 | 255
same than G_FONT_DEFAULT | G_FONT_SMALL | 32 | 255
Internal usage only (for the keyboard) | G_FONT_SYMBOL | 1 | 10

A lot of fonts is already available (but excluded from compilation due to memory limitation). To include / exclude a font, its corresponding symbol shall be commented / uncommented in file <app/resources/resources.h>:

Figure 8: font include / exclude

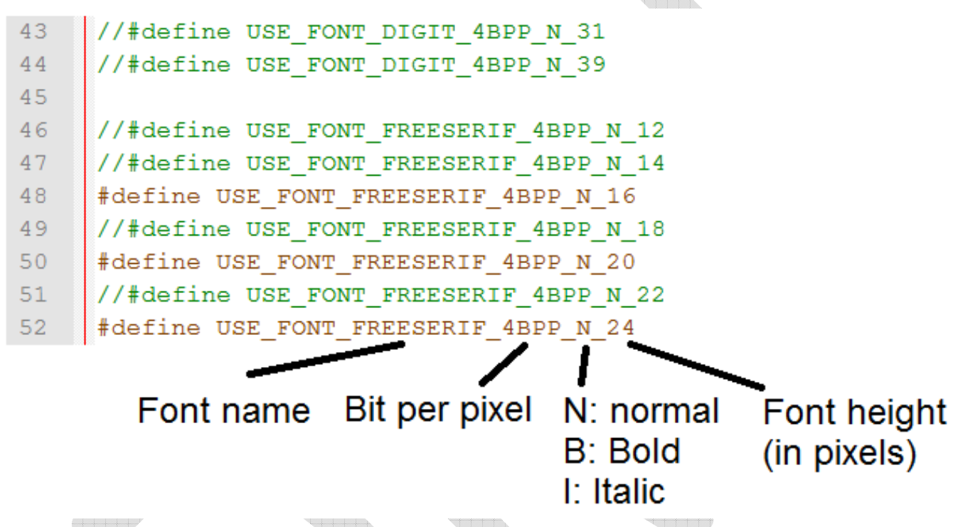
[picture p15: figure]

Developer Guide | 23 / 68

### 5. P2D

Some functions provided by P2D are not documented. These undocumented functions are mainly used by P2D itself.

### 5.1. Overview

P2D (stands for Primitives 2D) is a set of functions which perform basic graphical operations (e.g. draw a line, display a text or an image, etc…).

P2D is written in C language only.

### 5.1.1. Screen representation

The smart TFT (rev. a) is based on a graphical controller (ILI932x) which drives a 320x240 TFT screen. For now, P2D handles only one display orientation; the figure above shows how pixels are identified:

Figure 9: screen representation

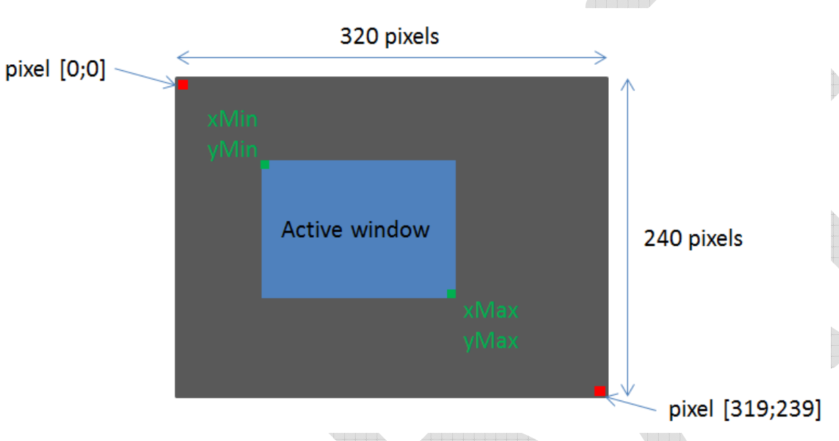
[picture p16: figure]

P2D needs some features provided by graphical controllers:
- Cursor placement: this feature allows P2D to place the cursor anywhere on the screen
- Cursor auto-increment: each time a pixel is put on the screen, the cursor is shifted to the right (x++); when reaching the right border, the cursor is automatically set to the left border of the next line (x = 0; y++)
- Hardware window: this feature allows to set the left and right borders used by the auto increment (delimited by xMin, yMin, xMax, yMax of Figure 9)
Other functionalities (e.g. hardware scrolling, hardware BitBlt or JPEG decompression provided by a SSD1926) are not used / supported.

### 5.1.2. Variables type & enumerations

Most P2D functions rely on specific data types listed below, and defined in ILI9320.h or P2D_base.h file:

Table 8: variables type

type | description
coord_t | Pixel coordinate (e.g. x or y) Equivalent to a 16bits signed integer; range [-32768 to 32767]

Developer Guide | 24 / 68
length_t | Length in pixel (i.e. length between 2 coordinates, in pixel. For x1 equal to x2, length is equal to 1) Equivalent to a 16 bits unsigned integer; range [0 to 65535]
typedef struct { coord_t x, y; length_t w, h; } rect_st; | Defines a rectangular surface, given by a point (x and y), a width w (the distance between xMax & xMin, in pixels) and a height h (the distance between yMax & yMin, in pixels). A valid rect_st shall fulfill w ≥ h ≥ 1
color_t | Color (standard RGB565 formatted). Equivalent to a 16 bits unsigned integer; 0x0000 ↔ black, 0xFFFF ↔ white
line_t | LINE_SOLID (draw a continuous line) LINE_DOT (draw a dotted line)
dmode_t | DISPLAY_SOLID DISPLAY_TRANSPARENT

### 5.1.3. Interface with the TFT

P2D is interfaced with few external functions, defined in ILI9320.h file, making easier the portability to another platform (see §10). These functions are listed below:

LCD_Init
description | Initializes the TFT screen (registers setting) and turns it ON
argument | none
return | none

LCD_GetWidth
description | Returns the TFT width, in pixels
argument | none
return | length_t | here, width = 320 pixels

LCD_GetHeight
description | Returns the TFT height, in pixels
argument | none
return | length_t | here, height = 240 pixels

LCD_SetWnd
description | Defines the hardware windows
argument | const rect_st *rec | new hardware window
return | none

LCD_SetPos
description | Sets the cursor position (i.e. the pixel which will be written next)
argument | coord_t x, y | new cursor position; the cursor position shall always be within the hardware windows dimension
return | none

Developer Guide | 25 / 68

LCD_Put
description | Sets the current pixel to a given color, and increment the cursor position; the cursor increment is always contained within the hardware window
argument | color_t col | RGB565 color
return | none

All functions provided by P2D rely on these 6 elementary functions.

### 5.2. Basic functions

Some functions come with some source code examples. To run these examples, just copy/paste the given code in file <src/app/user_app/user_app.c> at line 34; Do not forget to set the operational mode to embedded application (§3.7.2)

### 5.2.1. Initialization

The given source code already initializes P2D and its dependent software component. Nevertheless, this initialization is performed though the following function:

P2D_Init
description | Initializes the 2D primitives; Shall be called before using any P2D function. The following operations are performed: - Set destination to the physical screen - Set display mode as DISPLAY_SOLID - Set front/back colors to COLOR_BLACK - Set alpha to 255 (opaque) - Set line type to LINE_SOLID - Select the default font - Expand the clip to the screen dimensions - Clear the screen (COLOR_BLACK)
argument | none
return | none

### 5.2.2. Get LCD dimension

P2D_GetLcdWidth
description | Returns the width (in pixel) of the screen
argument | none
return | length_t | width (in pixels) of the screen
example | length_t w; w = P2D_GetLcdWidth(); // w = 320 here

P2D_GetLcdHeight
description | Returns the height (in pixel) of the screen
argument | none
return | length_t | height (in pixels) of the screen
example | length_t h; h = P2D_GetLcdHeight(); // h = 240 here

Developer Guide | 26 / 68

### 5.2.3. Colors

5.2.3.1.Format

As described in §5.1.2, the color is coded on 16 bits, following the RGB565 format, where the red channel is 5 bits width, green is 6 bits width and blue is 5 bits width:

R4 | R3 | R2 | R1 | R0 | G5 | G4 | G3 | G2 | G1 | G0 | B4 | B3 | B2 | B1 | B0

5.2.3.2.Colors conversion

Since it is not easy to write colors in this format, a function making the translation from RGB888 to RGB565 is available:

P2D_Color
description | Converts a standard RGB 888 into a RGB 565
argument | uint8_t r | red channel (0 to 255)
| uint8_t g | green channel (0 to 255)
| uint8_t b | blue channel (0 to 255)
return | color_t | RGB565 color
example | color_t color; color = P2D_Color(255, 0, 0); //red color color = P2D_Color(0, 255, 0); //green color color = P2D_Color(0, 0, 255); //blue color

The complementary function (conversion from RGB565 to RGB888) is also available:

P2D_ColorToRGB
description | Converts a RGB 565 into a RGB 888; introduces extrapolation errors!
argument | color_t color | RGB565 color input
| uint8_t *r | red channel (0 to 255) output
| uint8_t *g | green channel (0 to 255) output
| uint8_t *b | blue channel (0 to 255) output
return | none
example | uint8_t r, g, b; P2D_ColorToRGB(COLOR_GREEN, &r, &g, &b); /* normally, r should be = 0, g = 255, b = 0 * but due to extrapolation error, g will be != of 255 */

P2D_ColorBlackAndWhite
description | Turns a color into a black and white level
argument | color_t a | input color
return | color_t | output color (black & white)
example | color_t color; color = P2D_ColorBlackAndWhite(COLOR_RED);

P2D_Alpha_a_on_b
description | Computes the color value corresponding to alpha(color A on color B)
argument | color_t a | RGB565 color input
| color_t b | red channel (0 to 255) output
| uint8_t alpha | green channel (0 to 255) output

Developer Guide | 27 / 68
return | color_t | output color
example | color_t color; color = P2D_Alpha_a_on_b(COLOR_RED, COLOR_WHITE, 128);

5.2.3.3.Define the color to use

Colors to use shall be defined before using a drawing function (e.g. if you want to draw a red line, you shall set the color first). P2D handles 2 different colors:

- The front color: this color is used by most drawing functions (e.g. draw a pixel, a line, a rectangle…)
- The background color: this color is used only some functions (e.g. draw a sprite, draw a text), and is mainly ‘performance-oriented’.

P2D_SetColor
description | Sets the front color to use for next operations
argument | color_t front | new front color
return | none
example | P2D_SetColor(COLOR_RED); P2D_Clear(); //fills the screen in red

P2D_SetColors
description | Sets the front color and the background color to use for next operations
argument | color_t front | new front color
| color_t back | new background color
return | none
example | P2D_SetColors(COLOR_RED, COLOR_BLACK); P2D_SetDisplayMode(DISPLAY_SOLID); P2D_PutText(0, 0, "fastest text rendering");

5.2.3.4.Definitions

Some common colors are already defined in p2d_colors.h:

Table 9: defined colors

Symbol | R | G | B
COLOR_BLACK | 0 | 0 | 0
COLOR_DARK_GREY | 64 | 64 | 64
COLOR_GREY | 128 | 128 | 128
COLOR_LIGHT_GREY | 196 | 196 | 196
COLOR_WHITE | 255 | 255 | 255
COLOR_RED | 255 | 0 | 0
COLOR_ORANGE | 255 | 128 | 0
COLOR_YELLOW | 255 | 255 | 0
COLOR_GREEN | 0 | 255 | 0
COLOR_CYAN | 0 | 255 | 255
COLOR_BLUE | 0 | 0 | 255
COLOR_PURPLE | 255 | 0 | 255

### 5.2.4. Clear a surface

P2D_Clear

Developer Guide | 28 / 68
description | Clears the current surface within the current clip. The current surface may be the screen or an internal surface located memory (see §5.8 for internal surface, §5.2.5 for clipping)
argument | none
return | none
example | /*clear (in black) the whole screen*/ P2D_SetColor(COLOR_BLACK); P2D_SetClip(NULL); P2D_Clear(); /*clear (in white) a part of the screen*/ rect_st rec = {10, 20, 50, 50}; P2D_SetClip(&rec); P2D_SetColor(COLOR_WHITE); P2D_Clear();

### 5.2.5. Clipping

5.2.5.1.Introduction

The clipping module defines a display area; operations outside this area will not be performed. The above figure gives a typical example:

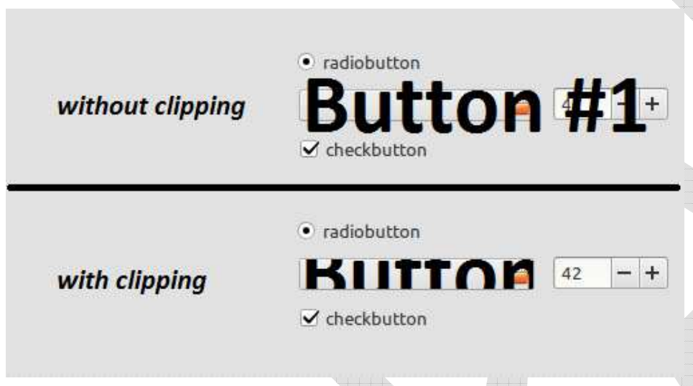
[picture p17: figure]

Figure 10: with / without clipping

Always configure the clip before putting anything on the screen (possible concurrent access with GUI)

All P2D drawing functions are delimited by the clipping.

5.2.5.2.Defining a clip

P2D_SetClip
description | Defines the global clip. All the following operations will be contained into this clip.
argument | const rect_st *rec | Clip to use; if NULL, the clip will be disabled (i.e. the clip is equal to the current surface dimension)
return | none
example | /*disable the clip (~expand to surface physical dimension)*/ P2D_SetClip(NULL); /*set a clip*/ rect_st rec = {10, 20, 50, 50}; P2D_SetClip(&rec); /*now, all drawing functions cannot modify pixels which do not belong to the defined rec*/

Developer Guide | 29 / 68

5.2.5.3.Operations on clip

P2D_IsCoordInClip
description | Checks if a given point is within the global clip
argument | coord_t x, y | Absolute coordinates of the given point
return | bool | if true, the point is within the clip
example | bool bIn; /*disable the clip (~expand to surface dimension)*/ P2D_SetClip(NULL); bIn = P2D_IsCoordInClip(1, 2); //true, [1;2] is within {0;0;320;240} /*set a clip*/ rect_st rec = {10, 20, 50, 50}; P2D_SetClip(&rec); bIn = P2D_IsCoordInClip(1, 2); //false, [1;2] is out of {10;20;50;50}

P2D_Clip
description | Modifies a given src clip in order to fit it in another given dst clip
argument | rect_st *src | a random clip; will be modified (if necessary) to fit into the dst clip
| const rect_st *dst | the reference clip
return | none
example | rect_st clipToFit = {0, 0, 320, 100}; rect_st clipRef_1 = {0, 0, 320, 240}; rect_st clipRef_2 = {20, 20, 300, 200}; P2D_Clip(&clipToFit, & clipRef_1); /*no change, clipToFit is smaller than clipRef_1*/ P2D_Clip(&clipToFit, & clipRef_2); /*clipToFit changed to {20, 20, 300, 100}*/

P2D_ClipFit
description | Modifies a given clip in order to fit it in the global clip. This is just a call to P2D_Clip() with the global clip as the dst argument.
argument | rect_st *toClip | a random clip; will be modified (if necessary) to fit into the global clip
return | none

### 5.2.6. Put a Pixel

P2D_SetPixel
description | Puts a pixel on the current surface
argument | coord_t x, y | Absolute coordinates of the given pixel
return | none
example | P2D_SetPixel(10, 20, COLOR_RED); //put a red pixel at x=10, y=20

Note: this function is not suitable for performance: for each pixel, this function checks if the given coordinates are within the global clip; as a consequence, this function cannot be used for achieving high performance drawing functions.

Developer Guide | 30 / 68

### 5.2.7. Draw a line

P2D_Line
description | Draws a line on the current surface
argument | coord_t x0, y0 | Absolute coordinates of the given pixel
| coord_t x1, y1
return | none
example | P2D_SetColor(COLOR_RED); P2D_Line(10, 20, 110, 120); //red a red line between 10;20 and 110;120

P2D_SetLineType
description | Sets the type of line (continuous or dotted)
argument | line_t type | LINE_SOLID for continuous line LINE_DOT for dotted line
return | none
example | P2D_SetColor(COLOR_GREY); P2D_Clear(); P2D_SetLineType(LINE_SOLID); P2D_SetColor(COLOR_RED); P2D_Line(10, 10, 100, 10); P2D_SetColors(COLOR_BLACK, COLOR_WHITE); P2D_SetLineType(LINE_DOT); P2D_Line(10, 20, 100, 20); P2D_SetDisplayMode(DISPLAY_TRANSPARENT); P2D_Line(10, 30, 100, 30);

### 5.2.8. Draw a rectangle

P2D_Rect
description | draw a rectangle
argument | const rect_st *rec | rectangle window
return | none

P2D_FillRect
description | draw a filled rectangle
argument | const rect_st *rec | rectangle window
return | none
example | P2D_SetColor(COLOR_GREY); P2D_Clear(); rect_st rec = {10,10,100,20}; P2D_SetColor(COLOR_RED); P2D_Rect(&rec); P2D_SetLineType(LINE_DOT); rec.y += 30; P2D_Rect(&rec); rec.y += 30; P2D_FillRect(&rec);

### 5.3. CLUTs

### 5.3.1. Introduction

Developer Guide | 31 / 68

CLUTs (Color Look-Up Tables) are used for saving memory without impacting performances (unlike jpg or png compression). It consists in reducing the number of colors composing an image (usually 2¹⁶ at least) into a color palette containing fewer colors (256 colors here; also known as color quantization). A 256 colors palette allows pixel to be coded with only one byte. By using optimal palette (provided by gimp), the 8bpp resulting image is quite identical to the 24bpp one, with much smaller memory footprint.

Figure 11: 24bpp vs 8bpp palletized

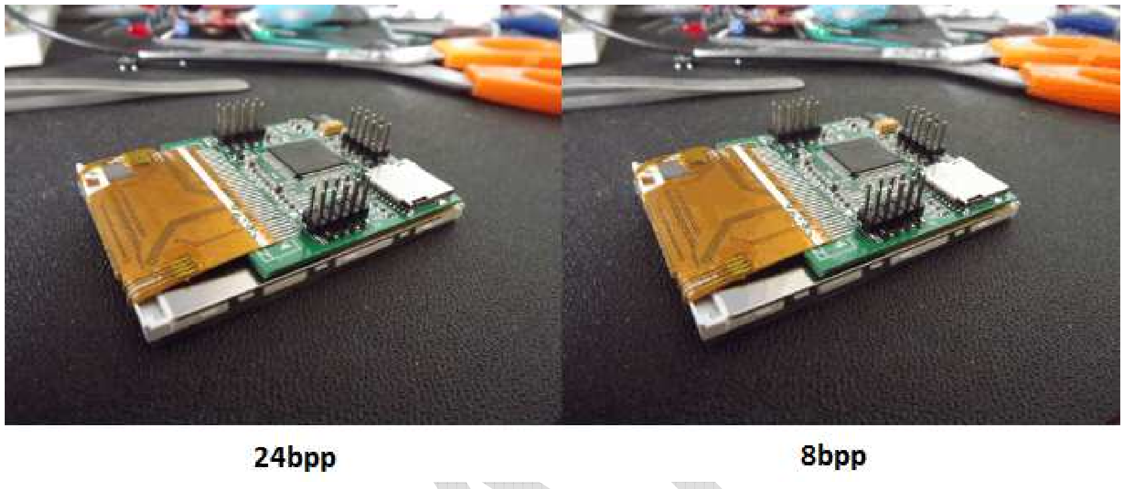
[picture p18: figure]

### 5.3.2. CLUT file description

CLUT file is very basic:
- The two first bytes compose a uint16, and represent the number of colors contained is the CLUT
- Each color entry is composed by 3 bytes, respectively red, green and blue channels.

Figure 12: CLUT file example

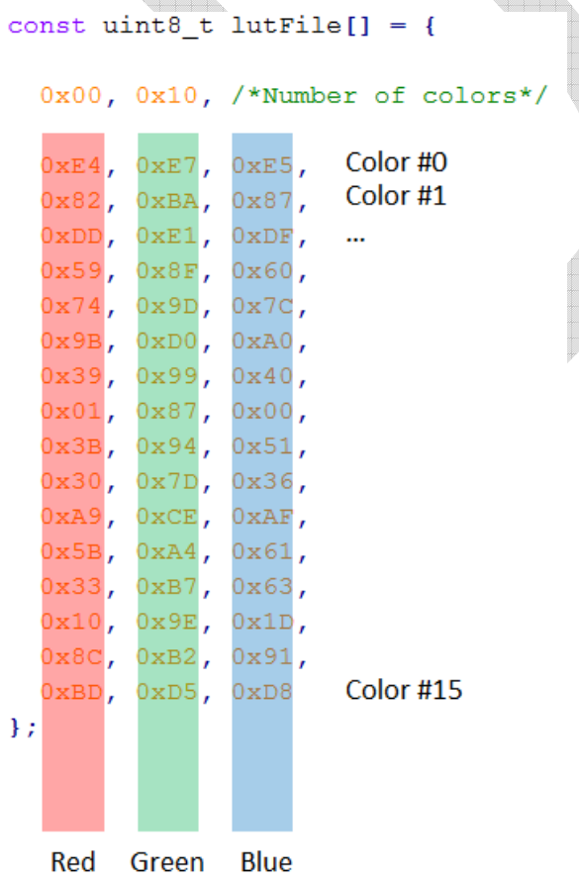
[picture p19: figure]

### 5.3.3. CLUT creation

Developer Guide | 32 / 68

P2D_InitLut8BPP
description | Initialize an 8BPP color LUT (256 different colors)
argument | lut8bpp_st *lut | Pointer to an already allocated lut8bpp_st struct
| const uint8_t *pFile | Pointer to a 8BPP CLUT file; can be NULL, depending of mode
| lutmode_t mode | CLUT configuration flags; see §5.3.5
return | int8_t | 0 if success, -1 otherwise
example | see §5.3.5

P2D_InitLut4BPP
description | Initialize a 4BPP color LUT (16 different colors)
argument | lut4bpp_st *lut | Pointer to an already allocated lut4bpp_st struct
| const uint8_t *pFile | Pointer to a 4BPP CLUT file; can be NULL, depending of mode
| lutmode_t mode | CLUT configuration flags; see §5.3.5
return | int8_t | 0 if success, -1 otherwise
example | see §5.3.5

### 5.3.4. CLUT update

P2D_UpdateLut4BPP
description | Update a 4BPP LUT: according to configuration flags and graphic context (e.g. front & background color), this function will re-compute each color composing the CLUT, only if needed.
argument | lut4bpp_st *lut | Pointer to an already allocated lut4bpp_st struct
return | none
example | see §5.3.5

P2D_UpdateLut8BPP
description | Update an 8BPP LUT: according to configuration flags and graphic context (e.g. front & background color), this function will re-compute each color composing the CLUT, only if needed.
argument | lut8bpp_st *lut | Pointer to an already allocated lut8bpp_st struct
return | none
example | see §5.3.5

### 5.3.5. CLUT configuration flags

Table 10: CLUT flags

Symbol | Description
LUT_E_COPY | Copies a LUT file into a lut4bpp_st / lut8bpp_st struct. This operation is used for loading the CLUT of the sprites. User shall give the *pFile to P2D_InitLut4BPP / P2D_InitLut8BPP
LUT_E_FILLED | Fills the whole CLUT with the current front color.
LUT_E_GRADIENT | Fills the whole CLUT with a color gradient (from front color to background color). For example, this configuration is used for AA text.

Developer Guide | 33 / 68
LUT_O_ALPHA | Apply an alpha value to the whole CLUT; can be summarized as “For each color, color = P2D_Alpha_a_on_b(color, background color, alpha)”
LUT_O_BLACK_AND_WHITE | Convert all colors of a CLUT to black & white levels
LUT_O_COLOR_KEY | If defined, the first color of a CLUT will be equal to the background color

### 5.4. Text

### 5.4.1. Font file description

A font file is composed of the following parts:

- A header, containing the font type (1 for 1BPP, 2 for 4BPP), the ASCII code of the first and the last printable glyphs and the font height (in pixel; all glyphs have the same height)
- An entry table: each glyph has a width (in pixel) and a memory offset to its “displayable” content. This offset is relative to the displayable content start address
- The displayable content (or raw), located just after the offset table end. For each glyph, this content describes all pixels composing the glyph, from top-left to bottom-right:

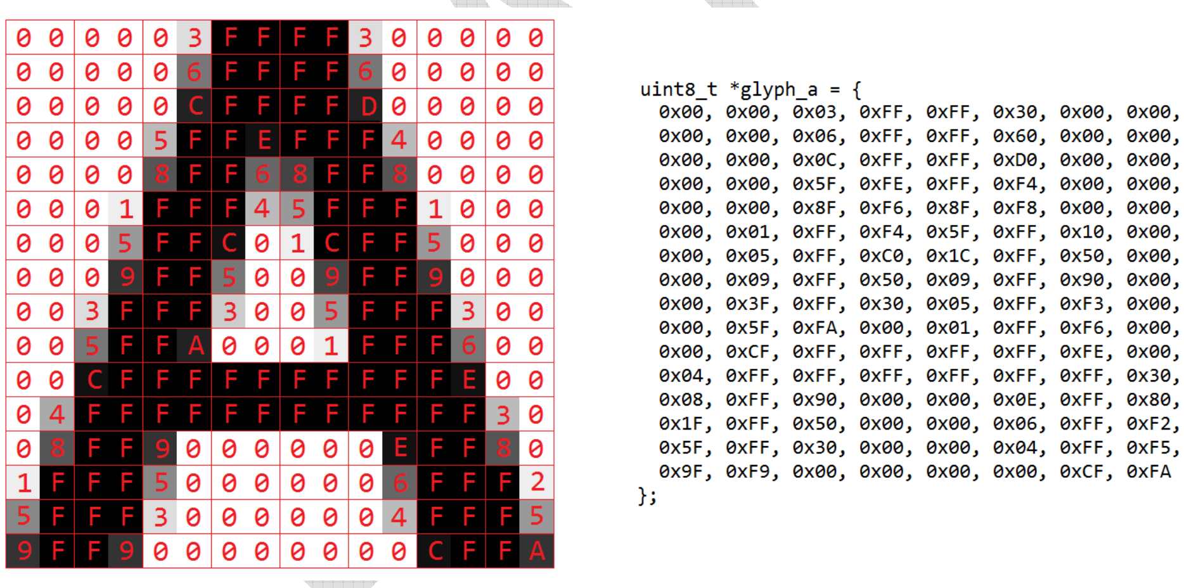
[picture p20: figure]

Figure 13: Glyph raw example

For 1BPP glyphs, each pixel is stored in one bit. For 4BPP glyphs, each pixel is stored in 4 bits representing an alpha level (between 0x0 and 0xF, where 0x0 means transparent and 0xF means opaque). A random byte from the displayable content section belongs to one – and only one – glyph (e.g. if the 1BPP glyph ‘A’ use only 2 bits of its last byte, then the glyph ‘B’ will not use the 6 remaining bits; glyphs do not share unused bits).

Developer Guide | 34 / 68

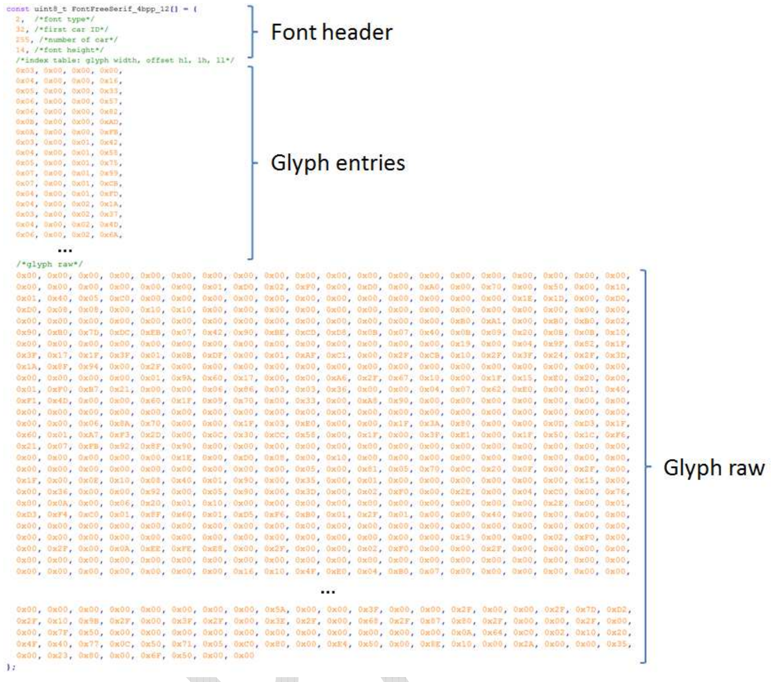
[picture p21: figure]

Figure 14: Font file example

### 5.4.2. Set a font

P2D_SetFont
description | Set the font to use for next font-related operations
argument | const uint8_t *pFile | Pointer to a font file. See resources.h header
return | int8_t | 0 if success, -1 otherwise
example | if(P2D_SetFont(FontFreeSerif_4bpp_n_16) < 0) { //error } else { //success }

### 5.4.3. Display some text

P2D_PutGlyph
description | Display a glyph at a given position, by using the font previously set by P2D_SetFont
argument | coord_t x, y | absolute coordinates of the top-left of the glyph
| uint8_t glyph | Glyph #id. If the glyph #id is not contained in the current font, nothing is displayed
return | none

Developer Guide | 35 / 68

P2D_PutText
description | Display a text at a given position, by using the font previously set by P2D_SetFont This functions does not handle ASCII controls (like ‘\n’)
argument | coord_t x, y | absolute coordinates of the top-left of the first glyph of the string
| const void *ptr | pointer to the string (‘\0’ terminated); will be internally casted in const uint8_t *
return | none
example | P2D_SetColor(COLOR_LIGHT_GREY); P2D_Clear(); P2D_SetColors(COLOR_BLACK, COLOR_LIGHT_GREY); P2D_SetFont(FontFreeSerif_4bpp_n_16); P2D_PutGlyph(10, 10, 'A'); P2D_PutText(10, 30, “hello world!”);

### 5.4.4. Get text dimension

P2D_GetTextHeight
description | Return the height (in pixel) of the current font, previously set by P2D_SetFont
argument | none
return | length_t | font height, in pixel

P2D_GetGlyphWidth
description | Return the width (in pixel) of a given glyph of the current font, previously set by P2D_SetFont
argument | uint8_t g | the given glyph; if the glyph does not exist in the current font, the function will return 0
return | length_t | glyph width, in pixel

P2D_GetTextWidth
description | Return the width (in pixel) of a ‘\0’ terminated string, by using the font previously set by P2D_SetFont. The string width is the sum of all glyphs width.
argument | const void *ptr | pointer to the string (‘\0’ terminated); will be internally casted in const uint8_t *
return | length_t | string width, in pixel
example | char *str = "hello world!"; coord_t x, y; P2D_SetColor(COLOR_LIGHT_GREY); P2D_Clear(); P2D_SetColors(COLOR_BLACK, COLOR_LIGHT_GREY); P2D_SetFont(FontFreeSerif_4bpp_n_16); x = LCD_GetWidth(); x -= P2D_GetTextWidth(str); x /= 2; y = LCD_GetHeight(); y -= P2D_GetTextHeight(); y /= 2; P2D_PutText(x, y, str);

### 5.5. Sprites

Developer Guide | 36 / 68

For now, only 8BPP sprites are implemented.

### 5.5.1. Sprite file description

Structure of a sprite file is quite similar to the font file one, and is composed of the following parts:

- A header, containing the sprite BPP (8 for 8BPP), the height and width of the sprite (in pixels, on 16 bits)
- The displayable content (or raw), located just after the header end. This content describes all pixels composing the sprite, from top-left to bottom-right:

Figure 15: Sprite file example

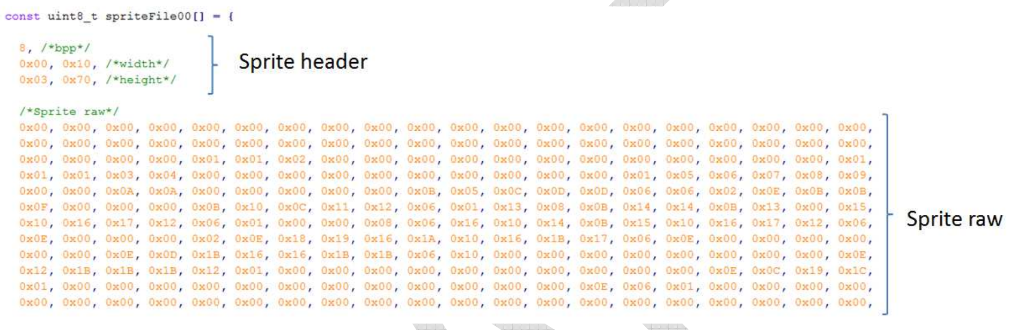
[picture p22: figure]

A sprite is always associated with a CLUT file; each pixel is defined by a color #id belonging to this CLUT.

### 5.5.2. Set a CLUT

P2D_SpriteSetLut8BPP
description | Define the CLUT to use for displaying sprites.
argument | const lut8bpp_st *lut | pointer to an already allocated CLUT
return | none
example | See §5.5.4

### 5.5.3. Get sprite dimension

P2D_SpriteGetHeight
description | Return the height (in pixel) of a given sprite
argument | const uint8_t *pFile | pointer to the sprite file
return | length_t | sprite height, in pixel; if the sprite does not exist, return 0

P2D_SpriteGetWidth
description | Return the width (in pixel) of a given sprite
argument | const uint8_t *pFile | pointer to the sprite file
return | length_t | sprite width, in pixel; if the sprite does not exist, return 0

### 5.5.4. Display a sprite

P2D_Sprite

Developer Guide | 37 / 68
description | Put a given sprite part on current surface, at given coordinates
argument | const rect_st *src | selected part of the sprite to display; if NULL, select the whole sprite
| const rect_st *dst | destination; only dst->x & dst->y are used
| const uint8_t *pFile | pointer to the sprite file
return | none

example

lut8bpp_st lut;
rect_st dst, src;
P2D_SetColors(COLOR_LIGHT_GREY, COLOR_LIGHT_GREY);
P2D_Clear();

/*load the CLUT in RAM memory*/
P2D_InitLut8BPP(&lut, spriteLutFile03, LUT_E_COPY | LUT_O_COLOR_KEY);

/*put the whole sprite at x=y=10*/
dst.x = 10; dst.y = 10;
P2D_SpriteSetLut8BPP(&lut);
P2D_Sprite(NULL, &dst, spriteFile03);

/*reload the CLUT in RAM memory, with alpha level*/ P2D_SetAlpha(64);
P2D_InitLut8BPP(&lut, spriteLutFile03, LUT_E_COPY | LUT_O_ALPHA |
LUT_O_COLOR_KEY);

/*put the whole sprite at x=50 y=10*/
dst.x = 50; dst.y = 10;
P2D_Sprite(NULL, &dst, spriteFile03);

/*reload the CLUT in RAM memory, with B&W transformation*/ P2D_InitLut8BPP(&lut, spriteLutFile03, LUT_E_COPY |
LUT_O_BLACK_AND_WHITE | LUT_O_COLOR_KEY);

/*put the whole sprite at x=90 y=10*/
dst.x = 90; dst.y = 10;
P2D_Sprite(NULL, &dst, spriteFile03);

/*put the a part of the sprite (defined by src) at x=130 y=10*/ src.x = 10; src.y = 10; src.w = 10; src.h = 100; dst.x = 130; P2D_Sprite(&src, &dst, spriteFile03);

### 5.6. Geometrics

### 5.6.1. Draw a circle

P2D_Circle
description | Draw a circle (1 pixel width)
argument | coord_t x0, y0 | center of the circle
| length_t radius | radius, in pixel
return | none

P2D_FillCircle
description | Draw a filled circle
argument | coord_t x0, y0 | center of the circle

Developer Guide | 38 / 68
| length_t radius | radius, in pixel
return | none
example | P2D_SetColor(COLOR_BLUE); P2D_Circle(50, 50, 10); P2D_SetColor(COLOR_RED); P2D_FillCircle(150, 100, 20);

### 5.6.2. Draw a polygon

Implementation of filled polygon is inspired from http://alienryderflex.com/polygon_fill/

Table 11: polygon-related variables type

type | description
typedef struct { coord_t x, y; } point_st; | Point definition for polygon-related functions

5.6.2.1.Defining a polygon

It consists in enumerating all points composing the polygon, as shown in the example below:

#define NB_POINT 5

const point_st myPolygon[NB_POINT] = { {260, 120}, //p1
{150, 170}, //p2
{40 , 165}, //p3
{140, 125}, //p4
{145, | 70} | //p5
};

5.6.2.2.Operation on points

Successive modifications on the same array (like zoom or rotate) should be avoided due to accumulation of rounding errors.

P2D_P_Copy
description | Copy an array of points into another given array. Used for avoiding rounding issues.
argument | const point_st *src | source array
| point_st *dst | destination array
| uint8_t nbPoint | number of points contained in the arrays
return | none

P2D_FindPolyCenter
description | Find the center of the polygon
argument | const point_st *arPoints | polygon points
| uint8_t nbPoint | number of points contained in the arrays

Developer Guide | 39 / 68
| point_st *center | returned center
return | none
example | #define NB_POINT 5 point_st center; point_st myPolygon[NB_POINT] = { {260, 120}, {150, 170}, {40 , 165}, {140, 125}, {145, 70} }; P2D_FindPolyCenter(myPolygon, NB_POINT, &center);

P2D_P_Move
description | Move a polygon
argument | point_st *arPoints | polygon points; will be overwritten
| uint8_t nbPoint | number of points contained in the arrays
| coord_t mvX, mvY | increment on x and y
return | none
example | #define NB_POINT 5 point_st myPolygon[NB_POINT] = { {260, 120}, {150, 170}, {40 , 165}, {140, 125}, {145, 70} }; P2D_P_Move(myPolygon, NB_POINT, 100, 50);

P2D_P_Zoom
description | Zoom a polygon according to a reference point
argument | point_st *arPoints | polygon points; will be overwritten
| uint8_t nbPoint | number of points contained in the arrays
| const point_st *ref | center of the zoom
| uint8_t zoomPercent | Zoom value, in percent (from 1% to 255%)
return | none

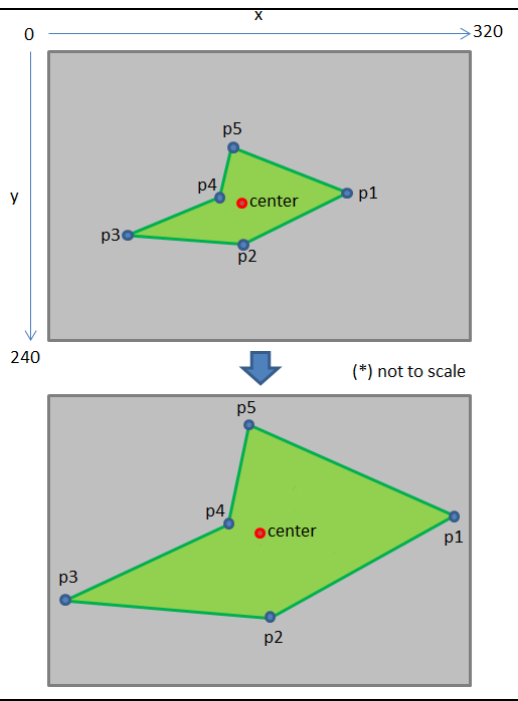
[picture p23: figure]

example | #define NB_POINT 5 point_st center; point_st myPolygon[NB_POINT] = { {260, 120}, {150, 170}, {40 , 165}, {140, 125}, {145, 70} }; P2D_FindPolyCenter(myPolygon, NB_POINT, &center); P2D_P_Zoom(myPolygon, NB_POINT, &center, 200);

Developer Guide | 40 / 68

P2D_P_Rotate
description | Rotate a polygon according to a reference point
argument | point_st *arPoints | polygon points; will be overwritten
| uint8_t nbPoint | number of points contained in the arrays
| const point_st *ref | center of the rotation
| uint16_t deg | rotation, in degrees
return | none
example | #define NB_POINT 5 point_st center; point_st myPolygon[NB_POINT] = { {260, 120}, {150, 170}, {40 , 165}, {140, 125}, {145, 70} }; P2D_FindPolyCenter(myPolygon, NB_POINT, &center); P2D_P_Rotate(myPolygon, NB_POINT, &center, 45);

5.6.2.3.Draw the polygon

P2D_Poly
description | Draw a polygon
argument | point_st *arPoints | polygon points
| uint8_t nbPoint | number of points of the polygon
return | none

P2D_FillPoly
description | Draw a filled polygon
argument | point_st *arPoints | polygon points
| uint8_t nbPoint | number of points of the polygon
return | none

5.6.2.4.Polygon example

Refer to <src/app/gui_demo/p2d_demo.c> file for a complete example.

### 5.6.3. Math functions

P2D_RandInit
description | Initialize the pseudo random generator
argument | uint32_t key | Seed value
return | none

Developer Guide | 41 / 68

P2D_RandInit
description | Return a pseudo random number between 0 and a given maximum
argument | uint16_t key | Maximum value
return | uint16_t | pseudo random value

P2D_Sin
description | Return sin(angle)
argument | int16_t deg | angle (in degrees)
return | int16_t | sin(angle); between -32767 and +32767 (P2D_G_DIV define)
example | float s; s = (float) P2D_Sin(90) / P2D_G_DIV;

P2D_Cos
description | Return cos(angle)
argument | int16_t deg | angle (in degrees)
return | int16_t | cos(angle); between -32767 and +32767 (P2D_G_DIV define)
example | float s; s = (float) P2D_Cos(90) / P2D_G_DIV;

P2D_Abs
description | Return abs(value)
argument | int32_t val | input value
return | int32_t | |val|

P2D_sqrt
description | Return √(value)
argument | uint16_t val | input value
return | uint8_t | √(value)

### 5.7. Utils

P2D_GetPixelCnt
description | Return the number of pixels contained in a given rect_st. Equivalent to rec->w * rec->h
argument | const rect_st *rec | input rect_st
return | uint32_t | number of pixels contained in *rec

P2D_GetLengthBtwnCoord
description | return the number of pixels between 2 coordinates belonging to the same type (e.g. x0 and x1 or y0 and y1, but not x0 and y0) Example: length between x0=10 and x1=13 is 4 (|x0-x1|+1: there are 4 pixels between 10 & 13)
argument | coord_t p0, p1 | coordinates to compare
return | length_t | length

P2D_CoordGetMin
description Return the lowest value between two coord_t

Developer Guide | 42 / 68
argument | coord_t p0, p1 | coordinates to compare
return | coord_t | lowest coord_t

P2D_CoordGetMax
description | Return the highest value between two coord_t
argument | coord_t p0, p1 | coordinates to compare
return | coord_t | highest coord_t

P2D_CoordGetDelta
description | Return |p0 - p1|
argument | coord_t p0, p1 | input coordinates
return | coord_t | |p0 - p1|

P2D_IsInClip
description | Check if a point is into a given rectangle
argument | const rect_st *rec | input rect_st
| coord_t p0, p1 | input coordinates
return | bool | true if the point is in the rect_st, false otherwise

P2D_RectToCoord
description | Convert a rect_st into absolute coordinates
argument | const rect_st *rec | input rect_st
| coord_t *x0, *y0, *x1, *y1 | output coordinates
return | int8_t | 0: success, -1: error (from NULL input pointer, or rec->w == 0 or rec->h == 0)

P2D_CoordToRect
description | Convert absolute coordinates into a rect_st
argument | rect_st *rec | output rect_st
| coord_t x0, y0, x1, y1 | input coordinates
return | int8_t | 0: success, -1: error (from NULL input pointer)

### 5.8. Internal buffering

This module is no longer maintained and may cause corruptions due to the memory allocator used. Nevertheless, this feature is usable if no memory is allocated before the surface destruction (see <src/app/gui_demo/p2d_demo.c> file for example)

### 5.8.1. Create an internal surface

P2D_SurfaceCreate
description | Create an internal surface (located in RAM memory)
argument | rect_st *rec | dimension of the surface (only w & h are used)

Developer Guide | 43 / 68
return | surfaceId_t

surface #id if success (range[SURFACE_1-(SURFACE_NUMBER-1)], SURFACE_LCD if error (e.g. not enough memory)

### 5.8.2. Set the destination

Destination switching (drawing on the screen or on a memory buffer) is made by redirecting the 5 basic interfaces (See §5.1.3). If the destination is hardware defined (i.e. the TFT screen), interfaces are linked to the ILI9320 driver; if the destination is software defined (i.e. internal buffered), interfaces are linked to local functions (in p2d_buffer.c file)

P2D_SetDest
description | Set the current surface; once set, all P2D operations will be performed on this surface
argument | surfaceId_t | desired surface destination
return | surfaceId_t | identical to the desired destination if success, SURFACE_LCD if error

### 5.8.3. Copy a surface to screen

P2D_CopySurface
description | Copy a part of a surface to the current one, at specified coordinates
argument | surfaceId_t | source surface (shall be != of the current one and != of SURFACE_LCD)
| const rect_st *src | dimension of the part of the source to copy; copy the whole source if NULL
| const rect_st *dst | destination coordinates (only x & y are used)
return | none

### 5.8.4. Delete an internal surface

P2D_SurfaceDelete
description | delete an internal surface and free the allocated memory ⁽¹⁾
argument | surfaceId_t | source surface (shall be != of the current one and != of SURFACE_LCD)
return | none
(1) The function calls sfreefrom(), which frees memory from the surface start address to the end of allocable area. This implies that nothing shall be allocated before deleting the surface; otherwise, when deleting the surface, next allocated objects will be erased or corrupted.

### 5.8.5. Example

Refer to <src/app/gui_demo/p2d_demo.c> file, where the flickering effect is avoided thanks to internal buffering usage.

Developer Guide | 44 / 68

### 6. GUI

### 6.1. Overview

GUI (stands for Graphical User Interface) is a set of functions which perform object-oriented graphical operations (e.g. draw & handle buttons, lists, sliders…).

GUI is written in C language only.

### 6.1.1. Generic object

This part is internally handled by the GUI, and is described only for documentation purpose. User should not directly access / modify such data

Each widget is derived from a GUI generic object (g_obj_st structure) that contains all common parameters, like position & dimension on screen, object group, attributes… Structure of generic object is defined in <app/gui/gui_obj.h> at line 52:

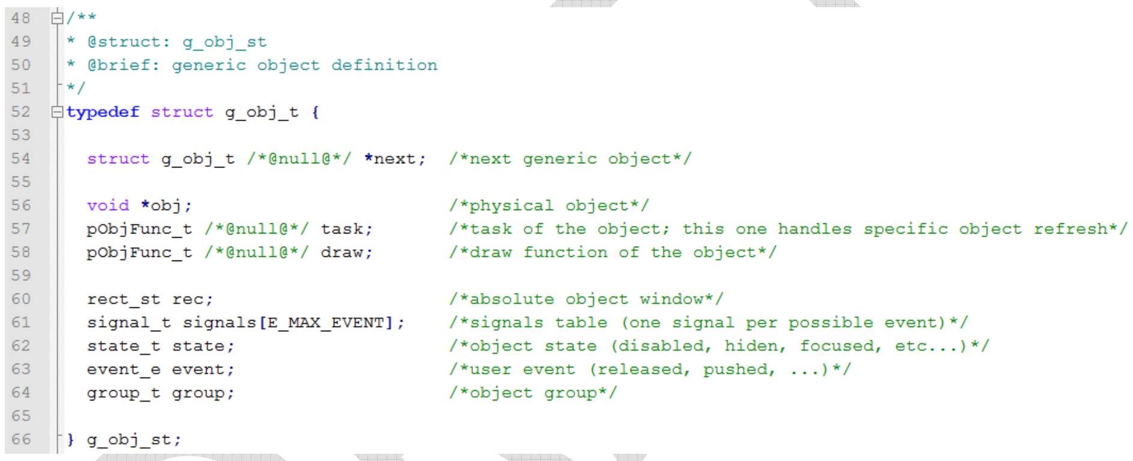
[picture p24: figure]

### 6.1.2. Object attributes

Each generic object has attributes, handled by the GUI itself. These attributes are listed above:

Table 12: generic object attribute

CLUT symbol | Description
NOTIFIED | Set by the user; if true, the GUI shall redraw the object every 500ms. The notification drawing is handled by the widget itself, and is not available for all widgets (e.g. a button is notifiable, a text area is not).
BLINK | Dynamically set by the GUI; toggles every 500ms, used for notification drawing
PRESSED | Dynamically set by the GUI; true if touchscreen area corresponding to the object is pressed.
DISABLED | Set by the user; if true, the GUI shall redraw the object by specifying to the widget the disable state (e.g. a disabled button will be displayed in gray levels, and will be stuck to released position)
FOCUSABLE | Set by the widget

Developer Guide | 45 / 68
FOCUSED | Dynamically set by the GUI; an object is focused if it is both focusable and pressed. (e.g. a focused button will be displayed with a dashed rectangle)
NEED_REFRESH | May be set by the GUI, the widget or the user; if true, the GUI shall redraw the object.
STATIC | Set by the widget; if true, GUI will not redraw the item if this one is pressed (e.g. a text area does not need to be redrawn if pressed, unlike a button)

GUI_ObjIsNotified
description | return the NOTIFIED flag of a generic object
argument | const g_obj_st *obj | pointer to the generic object
return | bool: true if notified, false otherwise

GUI_ObjSetNotified
description | set the NOTIFIED flag of a generic object
argument | const g_obj_st *obj | pointer to the generic object
| bool p | new flag value
return | none

GUI_ObjIsPressed
description | return the PRESSED flag of a generic object
argument | const g_obj_st *obj | pointer to the generic object
return | bool: true if pressed, false otherwise

GUI_ObjSetPressed
description | set the PRESSED flag of a generic object
argument | const g_obj_st *obj | pointer to the generic object
| bool p | new flag value
return | none

GUI_ObjIsDisabled
description | return the DISABLED flag of a generic object
argument | const g_obj_st *obj | pointer to the generic object
return | bool: true if disabled, false otherwise

GUI_ObjSetDisabled
description | set the DISABLED flag of a generic object
argument | const g_obj_st *obj | pointer to the generic object
| bool p | new flag value
return | none

GUI_ObjIsFocusable
description return the FOCUSABLE flag of a generic object

Developer Guide | 46 / 68
argument | const g_obj_st *obj | pointer to the generic object
return | bool: true if focusable, false otherwise

GUI_ObjSetFocusable
description | set the FOCUSABLE flag of a generic object
argument | const g_obj_st *obj | pointer to the generic object
| bool p | new flag value
return | none

GUI_ObjIsFocused
description | return the FOCUSED flag of a generic object
argument | const g_obj_st *obj | pointer to the generic object
return | bool: true if focused, false otherwise

GUI_ObjSetFocused
description | set the FOCUSED flag of a generic object
argument | const g_obj_st *obj | pointer to the generic object
| bool p | new flag value
return | none

GUI_ObjIsNeedRefresh
description | return the NEED_REFRESH flag of a generic object
argument | const g_obj_st *obj | pointer to the generic object
return | bool: true if need to refresh, false otherwise

GUI_ObjSetNeedRefresh
description | set the NEED_REFRESH flag of a generic object
argument | const g_obj_st *obj | pointer to the generic object
| bool p | new flag value
return | none

GUI_ObjIsStatic
description | return the STATIC flag of a generic object
argument | const g_obj_st *obj | pointer to the generic object
return | bool: true if static, false otherwise

GUI_ObjSetStatic
description | set the STATIC flag of a generic object
argument | const g_obj_st *obj | pointer to the generic object
| bool p | new flag value
return | none

### 6.1.3. Group

Generic objects can be grouped according to an id; this allows applying common attributes to several objects at the same time.

Developer Guide | 47 / 68

GUI_SetGroup
description | Set the current group value; this current group value will be used for the next created objects
argument | group_t g | new current group value
return | none

GUI_GroupDisable
description | Disable or enable all objects belonging to a given group
argument | group_t g | group to enable / disable
| bool p | new flag value
return | none

GUI_GroupNotify
description | Notify or not all objects belonging to a given group
argument | group_t g | group to notify
| bool p | new flag value
return | none

GUI_GroupRefresh
description | Refresh all objects belonging to a given group
argument | group_t g | group to refresh
| bool p | new flag value
return | none

### 6.1.4. Signals

For each object, GUI handles a small FSM composed of the following states:

- E_RELEASED: the object is released
- E_RELEASED_TO_PUSHED: the user has touched the object; this state lasts only one software cycle
- E_PUSHED: the object stays in this state while the user presses it.
- E_PUSHED_TO_RELEASED: the user has just released the object; this state lasts only one software cycle before going to E_RELEASED

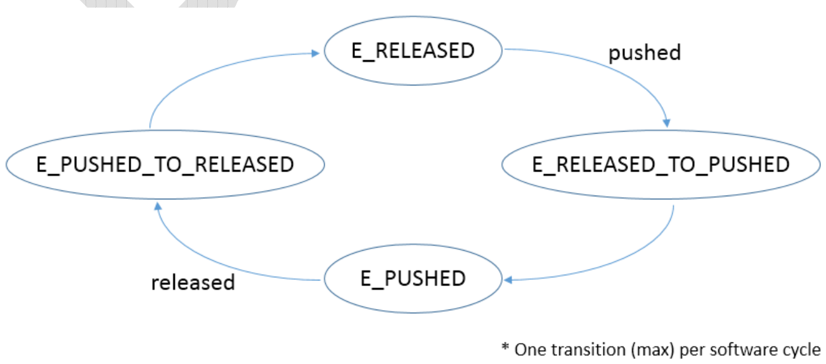
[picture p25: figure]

Figure 16: event FSM (simplified)

For each object, GUI allows to define a signal for each possible state through the following function:

Developer Guide | 48 / 68

GUI_SetSignal
description | associate a signal to an event for the last added object
argument | event_e event | Event (see Figure 16: event FSM)
| signal_t signal | Signal value (0 means no signal; useful signal from 1 to 0xFFFF)
return | none

See §6.1.5 for signal catching.

### 6.1.5. Page creation / page handling / page jump

todo

### 6.2. Widgets

### 6.2.1. Button

GUI_W_ButtonAdd
description | Add a basic button
argument | const rect_st *rec | button dimension & position
| const void *str | String of the button; can be NULL
| gui_img_t img | Image of the button; can be == 0 (no image)
return | g_obj_st | Pointer to the generic object if success, NULL if error

GUI_W_ButtonSetPlacementOrder
description | Define the placement of the text and the image of buttons
argument | btn_placeOrder_e order | G_BTN_PLACE_IMG_L_TEXT_R: image and text on the same y; image at left, text at right G_BTN_PLACE_IMG_R_TEXT_L: image and text on the same y; image at right, text at left G_BTN_PLACE_IMG_T_TEXT_B: image and text on the same x; image at top, text at bottom G_BTN_PLACE_IMG_B_TEXT_T: image and text on the same x; image at bottom, text at top
return | none
Example | rect_st rec = {10, 10, 100, 20}; GUI_W_ButtonAdd(&rec, "button1", G_IMG_NONE); rec.y += rec.h + 5; GUI_W_ButtonAdd(&rec, "button2", G_IMG_OK); rec.y += rec.h + 5; GUI_W_ButtonSetPlacementOrder(G_BTN_PLACE_IMG_R_TEXT_L); GUI_W_ButtonAdd(&rec, "button3", G_IMG_NO); rec.y += rec.h + 5; rec.h = 40; GUI_W_ButtonSetPlacementOrder(G_BTN_PLACE_IMG_T_TEXT_B); GUI_W_ButtonAdd(&rec, "button4", G_IMG_ADD); rec.y += rec.h + 5;

Developer Guide | 49 / 68

GUI_W_ButtonSetPlacementOrder(G_BTN_PLACE_IMG_B_TEXT_T); GUI_W_ButtonAdd(&rec, "button5", G_IMG_REMOVE);

### 6.2.2. Checkbox

GUI_W_CheckBoxAdd
description | Add a basic checkbox
argument | const rect_st *rec | checkbox dimension & position
| const void *str | String of the checkbox; can be NULL
| const uint8_t *pState | Pointer to the state of the checkbox; if *pState == 0, the checkbox is not ticked. The widget does not directly modify *pState; the user shall handle *pState manually
return | g_obj_st | Pointer to the generic object if success, NULL if error

Example

uint8_t check1 = check2 = check3 = check4 = check5 = 0;

rec = GUI_Rect(110, 25, 90, 19); GUI_W_CheckBoxAdd(&rec, "normal", &check1);

rec = GUI_Rect(110, 47, 90, 19); SetColor(G_COL_TEXT, P2D_Color(0, 140, 0)); GUI_W_CheckBoxAdd(&rec, "color", &check2); SetColor(G_COL_TEXT, P2D_Color(0, 0, 0));

rec = GUI_Rect(110, 69, 90, 19); SetFont(G_FONT_ITALIC);
GUI_W_CheckBoxAdd(&rec, "italic", &check3); SetFont(G_FONT_DEFAULT);

rec = GUI_Rect(110, 91, 90, 19); GUI_W_CheckBoxAdd(&rec, "notify me", &check4);

rec = GUI_Rect(110, 113, 90, 19); GUI_W_CheckBoxAdd(&rec, "disable me", &check5);

### 6.2.3. Radio

GUI_W_RadioAdd
description | Add a basic radio
argument | const rect_st *rec | radio dimension & position
| const void *str | String of the radio; can be NULL
| const uint8_t *pCurrentId | Pointer to the value of the #id of the selected radio; if *pCurrentId is equal to the radio’s #id, then the radio is ticked. The widget does not directly modify *pCurrentId; the user shall handle *pCurrentId manually

Developer Guide | 50 / 68
| uint8_t id | The #id of the radio
return | g_obj_st | Pointer to the generic object if success, NULL if error

Example

rec = GUI_Rect(210, 25, 90, 19); GUI_W_RadioAdd(&rec, "choice 1.a", &radio1, 1);

rec = GUI_Rect(210, 47, 90, 19); SetColor(G_COL_TEXT, P2D_Color(0, 0, 255)); GUI_W_RadioAdd(&rec, "choice 1.b", &radio1, 2); SetColor(G_COL_TEXT, P2D_Color(0, 0, 0));

rec = GUI_Rect(210, 69, 90, 19); SetFont(G_FONT_ITALIC);
GUI_W_RadioAdd(&rec, "choice 1.c", &radio1, 3); SetFont(G_FONT_DEFAULT);

rec = GUI_Rect(210, 113, 90, 19); GUI_W_RadioAdd(&rec, "default", &radio2, 1);

rec = GUI_Rect(210, 135, 90, 19); GUI_W_RadioAdd(&rec, "notify me", &radio2, 2);

rec = GUI_Rect(210, 157, 90, 19); GUI_W_RadioAdd(&rec, "disable me", &radio2, 3);

### 6.2.4. Frame

GUI_W_FrameAdd
description | Add a text frame
Argument | const rect_st *rec | frame dimension & position
| const void *str | String of the frame; can be NULL
return | g_obj_st | Pointer to the generic object if success, NULL if error
Example | rec = GUI_Rect(5, 0, 310, 215); SetFont(G_FONT_BOLD); GUI_W_FrameAdd(&rec, "P2D/GUI demo");

### 6.2.5. Text area

GUI_W_TextAdd
description | Add a text area
Argument | const rect_st *rec | area dimension & position
| const void *str | String of the area; can be NULL
return | g_obj_st | Pointer to the generic object if success, NULL if error
Example | rec = GUI_Rect(10, 20, 299, 137); GUI_W_TextAdd(&rec, "This program is free software: you can redistribute it and/or modify"

Developer Guide | 51 / 68

"it under the terms of the GNU General Public License as published by" "the Free Software Foundation, either version 3 of the License, or " "(at your option) any later version.");

rec.x--;
rec.y--;
rec.w += 2;
rec.h += 2;
P2D_SetLineType(LINE_SOLID); P2D_SetColor(COLOR_PURPLE); P2D_Rect(&rec);

### 6.2.6. Graph

GUI_W_GraphSetGridSpacing
description | set the grid spacing
Argument | length_t h | horizontal spacing, in pixel (min = 2px)
| length_t v | vertical spacing, in pixel (min = 2px)
return | none

GUI_W_GraphAdd
description | add graph container
Argument | const rect_st *rec | graph dimension & position
| e_grid_type grid | Grid type: GRAPH_GRID_DISABLED: no grid GRAPH_GRID_DOT_H: horizontal grid GRAPH_GRID_DOT_V: vertical grid GRAPH_GRID_DOT_HV: horizontal & vertical grid
| uint16_t refreshTime | refresh period, in ms
return | g_obj_st* | pointer to the associated generic object if succeeded, NULL if error

GUI_W_GraphAddCurveToGraph
description | add a curve into a graph container; number of curve not limited
Argument | g_obj_st *obj | pointer to the graph container
| uint8_t *data | pointer to the curve data (array of w uint8_t, where w is the width of the graph)
| color_t color | color of the curve
return | int8_t | 0 ok, -1 error

GUI_W_GraphAddSampleToCurve
description | add a sample to the curve; by using this function, corresponding curve will be considered as a circular buffer
Argument | g_obj_st *obj | pointer to the graph container

Developer Guide | 52 / 68
| uint8_t curveId | curve ID (the first curve has ID = 0)
| uint8_t sample | new sample
return | none

Refer to <src/app/gui_demo/gui_demo_graph1.c> and <src/app/gui_demo/gui_demo_graph2.c> for examples.

### 6.2.7. Led

GUI_W_LedAdd
description | Add a text area
Argument | const rect_st *rec | Led dimension & position
| const void *str | String of the led; can be NULL
| const uint8_t *pState | pointer to the state of the led (red if *pState == 0, green otherwise)
return | g_obj_st | Pointer to the generic object if success, NULL if error
Example | uint8_t a = 0, b = 1; rect_st rec = GUI_Rect(10, 10, 100, 17); GUI_W_LedAdd(&rec, "My LED #A", &a); rec.y += 20; GUI_W_LedAdd(&rec, NULL, &b);

### 6.2.8. List

See §6.3.3

### 6.2.9. Slider

GUI_W_SliderAdd
description | Add a slider
Argument | const rect_st *rec | area dimension & position
| uint8_t *pValue | Pointer to the slider value (in & out)
return | g_obj_st | Pointer to the generic object if success, NULL if error
Example | rect_st rec; uint8_t u8Slider = 64; rec = GUI_Rect(20, 165, 255, 15); GUI_W_SliderAdd(&rec, &u8Slider); rec = GUI_Rect(285, 117, 15, 85); GUI_W_SliderAdd(&rec, &u8Slider);

Developer Guide | 53 / 68

### 6.2.10. Value box

todo

### 6.2.11. Dial

todo

### 6.2.12. Value box (special Dial)

todo

### 6.2.13. User entry

todo

### 6.3. Macros

todo

### 6.3.1. Keyboard

todo

### 6.3.2. Popup

todo

### 6.3.3. Lists (macro)

todo

### 6.3.4. Files browser

todo

Developer Guide | 54 / 68

### 7. SD card

The smart TFT includes the FatFS from http://elm-chan.org/fsw/ff/00index_e.html which has been adapted to the PIC32 by following thread http://www.microchip.com/forums/m563218.aspx

The µSD card is mounted once, at startup. File system will not be available if the µSD card is plugged later, at runtime.

Refer to the official FatFS documentation available at http://elm-chan.org/fsw/ff/00index_e.html

### 8. RAM memory organization

This part is internally handled by the smart TFT, and is described only for documentation purpose. User should not modify memory management

The RAM memory is split in 4 areas:
- Allocable: this contiguous area is used by the custom memory allocator, for dynamically providing memory to the GUI (default size = 100KB)
- SSM: shared memory between the smart TFT and a remote master (default size = 5KB)
- Data: few KB, composed of scattered small areas, defined by the compiler itself for storing program data
- Unused: few remaining KB, not used, available for user.

This chapter deals with the allocable and SSM memory areas.

### 8.1. Memory allocator

The smart TFT uses a custom memory allocator (stack allocator like) which acts as follow:

1) A contiguous bounded area is defined at compilation time (here 100KB). A stack pointer is used to store the next allocable address
2) When a widget asks for memory (through salloc() function), the allocator shares a part of its area and updates its stack pointer. After a memory allocation, the stack pointer will always be aligned to the upper address aligned @4, if not already aligned.

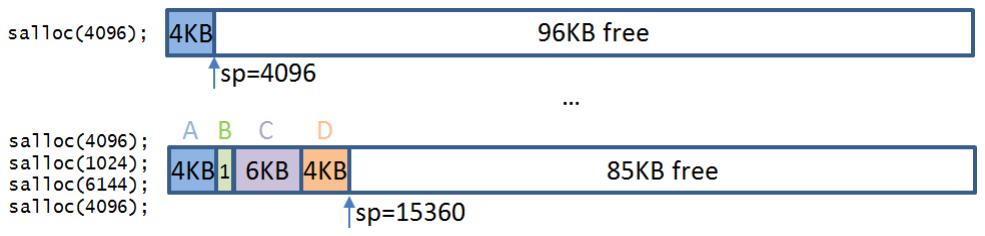
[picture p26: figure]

3) Unlike the standard free() function which allows to release any allocated area (e.g. release only the B area), the custom allocator can only release from an allocated area address (e.g. releasing B will also release C and D), through the sfreefrom() function.

Developer Guide | 55 / 68

Notice that the sfreefrom() function will only update the stack pointer; content of B, C & D will not be modified until the next allocation.

This strange releasing policy may be considered as a drawback, but has actually some advantages:
- It is simple to implement, and is very fast to execute (equivalent to o(1) complexity)
- Since the allocation is contained in a bounded area, and since memory releasing is from a defined address (handled by the GUI, when creating a new page), memory leaks are not possible.
- Implementation of widgets destructors is useless

### 8.2. Allocable memory organization

At runtime, allocable memory could be split in 3 parts:
- Graphics: at startup, the GUI registers graphical resources to make their exploitation easier (e.g. a sprite will be handled with a simple #id instead of a pointer to a sprite file + a pointer to a CLUT file). Output of this registration is stored once, at the very beginning of allocable memory.
- Base layer objects: once the graphic registration completed, the GUI save the current stack pointer of the allocator. This pointer will remain constant and will be referenced as the address to use with sfreefrom() when clearing a page.
- Top layer objects: some macros (e.g. the built-in keyboard) use the top layer. When the top layer is opened, the GUI saves the current stack pointer of the allocator. This pointer will be used with sfreefrom() when closing the top layer.

### 8.3. Serialized Shared Memory

This part is effective only if the operational mode is defined to slave (see §3.7)

Developer Guide | 56 / 68

Some widgets need locally-referenced variables to work (e.g. a checkbox shall be linked to a uin8_t, and will display – or not – the tick according to this uint8_t value). The Serialized Shared Memory module is a small software part providing reading, writing and referencing services through a serial communication port.

The SSM module handle a small memory area (default size = 2KB) which is shared between a master (through UART) and the smart TFT itself. This memory area is accessed by offsets instead of addresses, where offset #0 is the start address of the area, offset #1 is the start address + 1 …

The following functions are provided:

SSM_WriteU8
description | Write an uint8_t at a given offset
Argument | uint16_t offset | offset, @1 aligned
| uint8_t val | new value to write
return | int8_t | 0 success, -1 error (e.g. invalid offset)

SSM_WriteU16
description | Write an uint16_t at a given offset
Argument | uint16_t offset | offset, @2 aligned
| uint16_t val | new value to write
return | int8_t | 0 success, -1 error (e.g. invalid offset)

SSM_WriteI16
description | Write an int16_t at a given offset
Argument | uint16_t offset | offset, @2 aligned
| int16_t val | new value to write
return | int8_t | 0 success, -1 error (e.g. invalid offset)

SSM_WriteU32
description | Write an uint32_t at a given offset
Argument | uint16_t offset | offset, @4 aligned
| uint32_t val | new value to write
return | int8_t | 0 success, -1 error (e.g. invalid offset)

SSM_WriteI32
description | Write an int32_t at a given offset
Argument | uint16_t offset | offset, @4 aligned
| int32_t val | new value to write
return | int8_t | 0 success, -1 error (e.g. invalid offset)

SSM_ReadU8
description | Read an uint8_t at a given offset
Argument | uint16_t offset | offset, @1 aligned
| uint8_t *val | read result
return | int8_t | 0 success, -1 error (e.g. invalid offset)

Developer Guide | 57 / 68

SSM_ReadU16
description | Read an uint16_t at a given offset
Argument | uint16_t offset | offset, @2 aligned
| uint16_t *val | read result
return | int8_t | 0 success, -1 error (e.g. invalid offset)

SSM_ReadI16
description | Read an int16_t at a given offset
Argument | uint16_t offset | offset, @2 aligned
| int16_t *val | read result
return | int8_t | 0 success, -1 error (e.g. invalid offset)

SSM_ReadU32
description | Read an uint32_t at a given offset
Argument | uint16_t offset | offset, @4 aligned
| uint32_t *val | read result
return | int8_t | 0 success, -1 error (e.g. invalid offset)

SSM_ReadI32
description | Read an int32_t at a given offset
Argument | uint16_t offset | offset, @4 aligned
| int32_t *val | read result
return | int8_t | 0 success, -1 error (e.g. invalid offset)

The example below shows the implementation of a simple radio, both at TFT side and master side:

TFT side (embedded app mode) | Master side (slave mode)
#define SIG_CHK 1 uint8_t chk1 = 0; void MyPageCreate(void) { rect_st rec; rec = GUI_Rect(210, 25, 90, 19); GUI_W_CheckBoxAdd(&rec, "check", &chk1); GUI_SetSignal(E_PUSHED_TO_RELEASED,SIG_CHK); ... } void MyPageHandle(signal_t sig) { if(sig == SIG_CHK) chk1 = !chk1; } | #define SIG_CHK 1 #define ADDR_CHK1 0 uint8_t chk1 = 0; void MyPageCreate(void) { rect_st rec; rec = GUI_Rect(210, 25, 90, 19); R_GUI_W_CheckBoxAdd(&rec,"check",ADDR_CHK1); R_MEM_WriteU8(ADDR_CHK1, chk1); GUI_SetSignal(E_PUSHED_TO_RELEASED,SIG_CHK); ... } void MyPageHandle(signal_t sig) { if(sig == SIG_CHK) { chk1 = !chk1; R_MEM_WriteU8(ADDR_CHK1, chk1); } }

At TFT side, the radio is just linked to its variable; at master side, the radio is linked to a uint8_t located in the SSM area at offset #0.

Developer Guide | 58 / 68

### 9. UART driving

This part is still under development

Limitation: for now, UART driving supports only the PIC32 endianness. This implies that the system used for driving the smart TFT shall send LITTLE_ENDIAN data.

Communication between the smart TFT and a master is half-duplex oriented; the master shall always wait for an answer before sending a new message.

An UART driving example (master side) is given in folder <remote_example>

The following chart will be applied for this whole paragraph:

Box color | Description
| indicates an unsigned char (uint8_t) parameter
| indicates a signed char (int8_t) parameter
| indicates an unsigned short (uint16_t) parameter
| indicates a signed short (int16_t) parameter
| indicates an unsigned integer (uint32_t) parameter
| indicates a signed integer (int32_t) parameter
| string (‘\0’ terminated) parameter

### 9.1. Message

A message (both from master to TFT or TFT to master) is constituted of 3 parts:
- Start sequence, defined by two successive TOKEN_START (x55) plus a sequence number (seq)
- User message, variable sized
- Stop sequence, defined by two successive TOKEN_STOP (xAA)

Figure 17: message structure

To avoid untimely stop sequences in the user message, a TOKEN_SKIP (xFE) is automatically inserted when the user message contains two successive xAA bytes. The TOKEN_SKIP acts the same way than the backslash ‘\’ in a C file:

useful content to send | actual sent content
x01 xAA xAA x02 | x01 xAA xFE xAA x02
x01 xFE x02 | x01 xFE xFE x02

Developer Guide | 59 / 68

The sequence number is just a robustness feature handled at master side. For each received message, the smart TFT just echoes the sequence number to the master, ensuring that the processed message is the expected one. The sequence number can be stuck by the master to a constant value if not used.

### 9.2. User message (from master to smart TFT)

The user message contains a variable-sized list of variable-sized commands: a message can contain just one operation (e.g. clear the screen – 1 byte), or several operations (e.g. clear the screen – 1 byte, set red color – 3 bytes, and draw a line – 9 bytes).

Available commands are listed in §Serialized commands9.4.

A user message (from master to smart TFT) example is given below:

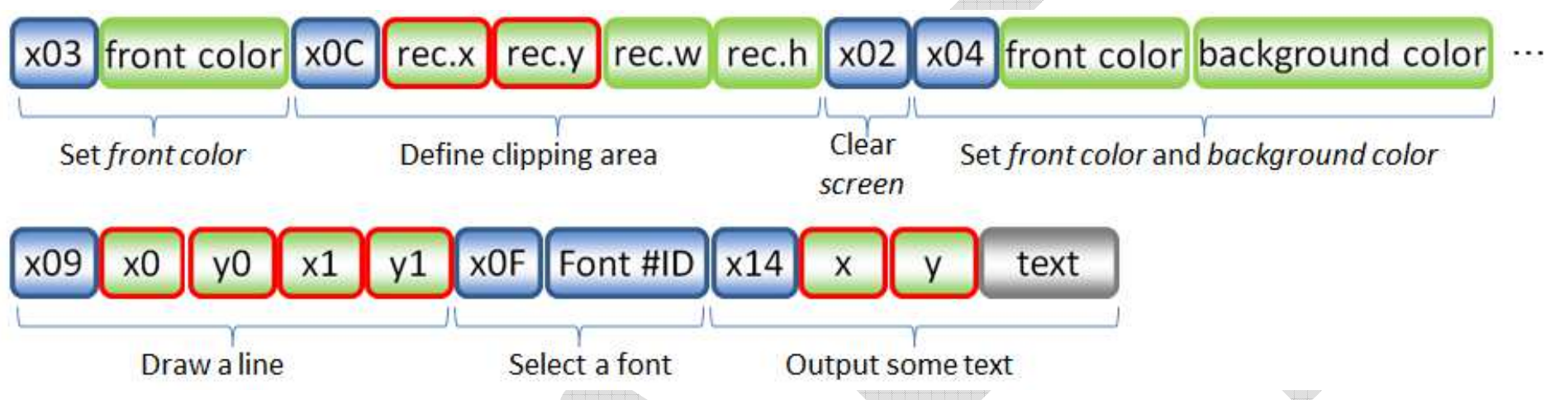
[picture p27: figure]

### 9.3. Answer message (from smart TFT to master)

Each time a message is received, the smart TFT processes it and sends back an answer message to the master. This answer message has the same form than described in §9.1. According to commands previously received, the answer size may vary; e.g.:

received message | answer content
clear the screen set RED color draw a line | 0x00 (1 byte) ↔ success
write a byte located at offset = invalid | 0xFF (1 byte) ↔ error
read the byte located at offset = 10 get screen width read the string located at offset = 200 | byte at offset = 10 (1 byte), screen width (2 bytes), string at offset = 200 (n bytes), 0x00 (success, 1 byte)

### 9.4. Serialized commands

Each command is described as follow:

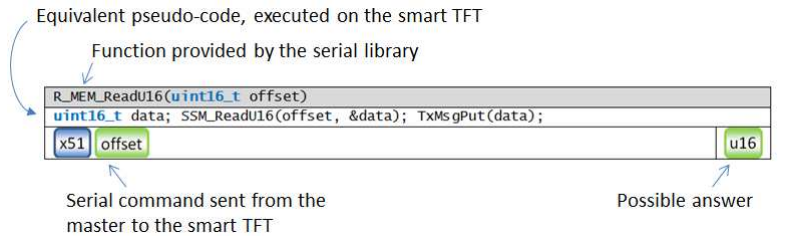
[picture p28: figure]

Figure 18: command description

Developer Guide | 60 / 68

reserved
reserved

R_GUI_Debug(bool bDisplay) GUI_DBG_DispMemUsage(bDisplay); --

R_P2D_Clear(void)
P2D_Clear();

R_P2D_SetColor(color_t front_folor) P2D_SetColor(front_color);

R_P2D_SetColors(color_t front_folor, color_t background_color) P2D_SetColors(front_color, background_color);

R_P2D_SetDisplayMode(dmode_t mode) P2D_SetDisplayMode(mode);

R_P2D_P2D_SetAlpha (uint8_t alpha) P2D_SetAlpha(alpha);

R_P2D_SetLineType(line_t type) P2D_SetLineType(type);

R_P2D_SetPixel(coord_t x, coord_t y, color_t color) P2D_SetPixel(x, y, color);

R_P2D_Line(coord_t x0, coord_t y0, coord_t x1, coord_t y1) P2D_Line(x0, y0, x1, y1);

R_P2D_Rect(rect_st *rec)
P2D_Rect(&rec);

R_P2D_FillRect(rect_st *rec) P2D_FillRect(&rec);

Developer Guide | 61 / 68

R_P2D_SetClip(rect_st *rec) P2D_SetClip(&rec);

R_P2D_GetLcdWidth(void)
w = P2D_GetLcdWidth(); TxMsgPut(w);

R_P2D_GetLcdHeight(void)
h = P2D_GetLcdHeight(); TxMsgPut(h);

R_P2D_SetFont(gui_font_t font) SetFont(font_id);

R_P2D_GetTextHeight(void)
h = P2D_GetTextHeight(); TxMsgPut(h);

R_P2D_GetTextWidth(void *str)
w = P2D_GetTextWidth(text); TxMsgPut(w);

R_P2D_GetGlyphWidth(uint8_t glyph)
w = P2D_GetGlyphWidth(glyph); TxMsgPut(w);

R_P2D_PutGlyph(coord_t x, coord_t y, uint8_t glyph) P2D_PutGlyph(x, y, glyph);

R_P2D_PutText(coord_t x, coord_t y, void *str) P2D_PutText(x, y, text);

R_P2D_Circle(coord_t x, coord_t y, length_t radius) P2D_Circle(x, y, radius);

R_P2D_FillCircle(coord_t x, coord_t y, length_t radius) P2D_FillCircle(x, y, radius);

R_P2D_Poly(uint8_t nb_Point, point_st *points) P2D_Poly(&points, nb_points);

Developer Guide | 62 / 68

R_P2D_FillPoly(uint8_t nb_Point, point_st *points) P2D_FillPoly(&points, nb_points);

R_P2D_SpriteGetWidth(gui_img_t sprite_id) w = SpriteGetWidth(sprite_id); TxMsgPut(w);

R_P2D_SpriteGetHeight(gui_img_t sprite_id) h = SpriteGetHeight(sprite_id); TxMsgPut(h);

R_SetLut(uint8_t clut_id)
SetLut(clut_id);

R_Sprite(coord_t x, coord_t y, gui_img_t sprite_id) Sprite(x, y, sprite_id);

reserved
reserved

reserved
reserved

reserved
reserved

R_GUI_GetLastAddedObject(uint16_t offset) ssm[offset] = GUI_GetLastAddedObject(); --

R_GUI_ReadSignal(void)
TxMsgPut(GUI_ReadLastSignal());

R_GUI_SetAlign(gui_align_t align) GUI_SetAlign(align);

R_GUI_SetColor(uint16_t color_id, color_t color) SetColor(color_id, color)

Developer Guide | 63 / 68

R_GUI_ClearAll(void)
GUI_ClearAll()

R_GUI_SetGroup(group_t group) GUI_SetGroup(group);

R_GUI_SetSignal(event_e event, signal_t signal) GUI_SetSignal(event, signal);

R_GUI_GroupDisable(group_t group, bool bDisable) GUI_GroupDisable(group, bDisable);

R_GUI_GroupNotify(group_t group, bool bNotify) GUI_GroupNotify(group, bNotify);

R_GUI_GroupRefresh(group_t group, bool bRefresh) GUI_GroupRefresh(group, bRefresh);

R_GUI_W_ButtonSetPlacementOrder(btn_placeOrder_e align) GUI_W_ButtonSetPlacementOrder(align);

R_GUI_W_ButtonAdd(rect_st *rec, void *text, gui_img_t sprite_id) GUI_W_ButtonAdd(&rec, text, sprite_id);

R_GUI_W_CheckBoxAdd(rect_st *rec, void *text, uint16_t offset) GUI_W_CheckBoxAdd(&rec, text, &ssm[offset]);

R_GUI_W_FrameAdd(rect_st *rec, void *text) GUI_W_FrameAdd(&rec, text);

R_GUI_W_GraphSetGridSpacing(length_t hSpacing, length_t vSpacing) GUI_W_GraphSetGridSpacing(hSpacing, vSpacing);

R_GUI_W_GraphAdd(rect_st *rec, uint8_t grid, uint16_t refresh_tm) GUI_W_GraphAdd(&rec, grid, refresh_tm);

Developer Guide | 64 / 68

R_GUI_W_GraphAddCurveToGraph(uint16_t offset, color_t color) GUI_W_GraphAddCurveToGraph(NULL, &ssm[offset], color);

R_GUI_W_GraphAddSampleToCurve(uint16_t offset_obj, uint8_t curve_id, uint8_t sample)
GUI_W_GraphAddSampleToCurve(ssm[offset_obj], curve_id, sample);

R_GUI_W_LedAdd(rect_st *rec, void *text, uint16_t offset) GUI_W_LedAdd(&rec, text, &ssm[offset]);

R_GUI_W_RadioAdd(rect_st *rec, void *text, uint16_t offset, uint8_t id) GUI_W_RadioAdd(&rec, text, &ssm[offset], id);

R_GUI_W_RotaryButtonAdd(rect_st *rec, uint16_t offset, gr_enum_e granularity) GUI_W_RotaryButtonAdd(&rec, &ssm[offset], granularity);

R_GUI_W_RotaryValueAdd(rect_st *rec, uint16_t off_I32, uint16_t off_I8, void *text)
GUI_W_RotaryValueAdd(&rec, &ssm[off_I32], &ssm[off_I8], text);

R_GUI_W_RotaryValueLock(uint16_t offset_obj, bool bLock) GUI_W_RotaryValueLock(ssm[offset_obj], bLock);

R_GUI_W_RotaryValueSetMinMax(int32_t min, int32_t max) GUI_W_RotaryValueSetMinMax(NULL, min, max);

R_GUI_W_RotaryValueSetDotPos(uint8_t pos_dot) GUI_W_RotaryValueSetDotPos(NULL, pos_dot); --

reserved
reserved

R_GUI_W_SliderAdd(rect_st *rec, uint16_t offset) GUI_W_SliderAdd(&rec, &ssm[offset]);
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

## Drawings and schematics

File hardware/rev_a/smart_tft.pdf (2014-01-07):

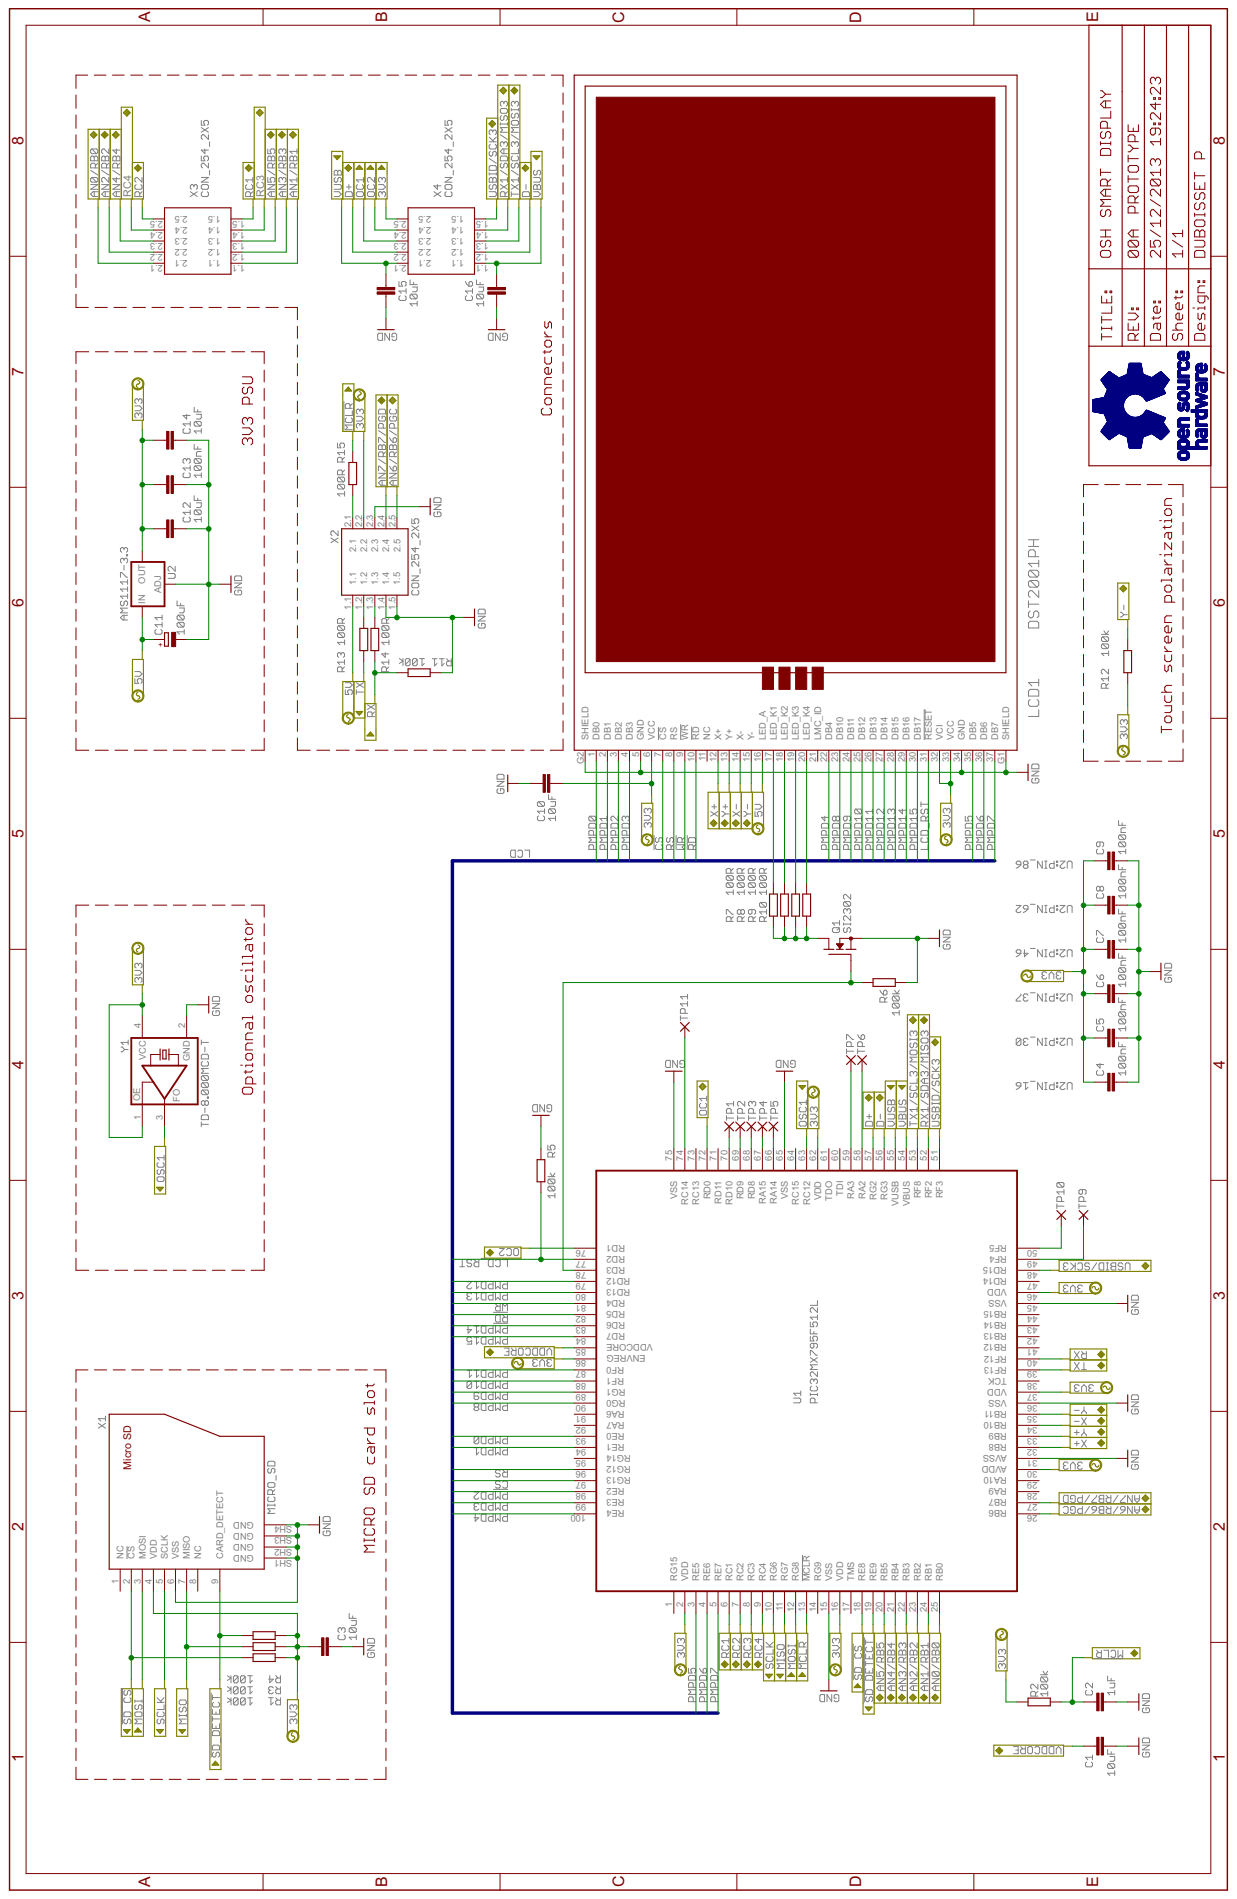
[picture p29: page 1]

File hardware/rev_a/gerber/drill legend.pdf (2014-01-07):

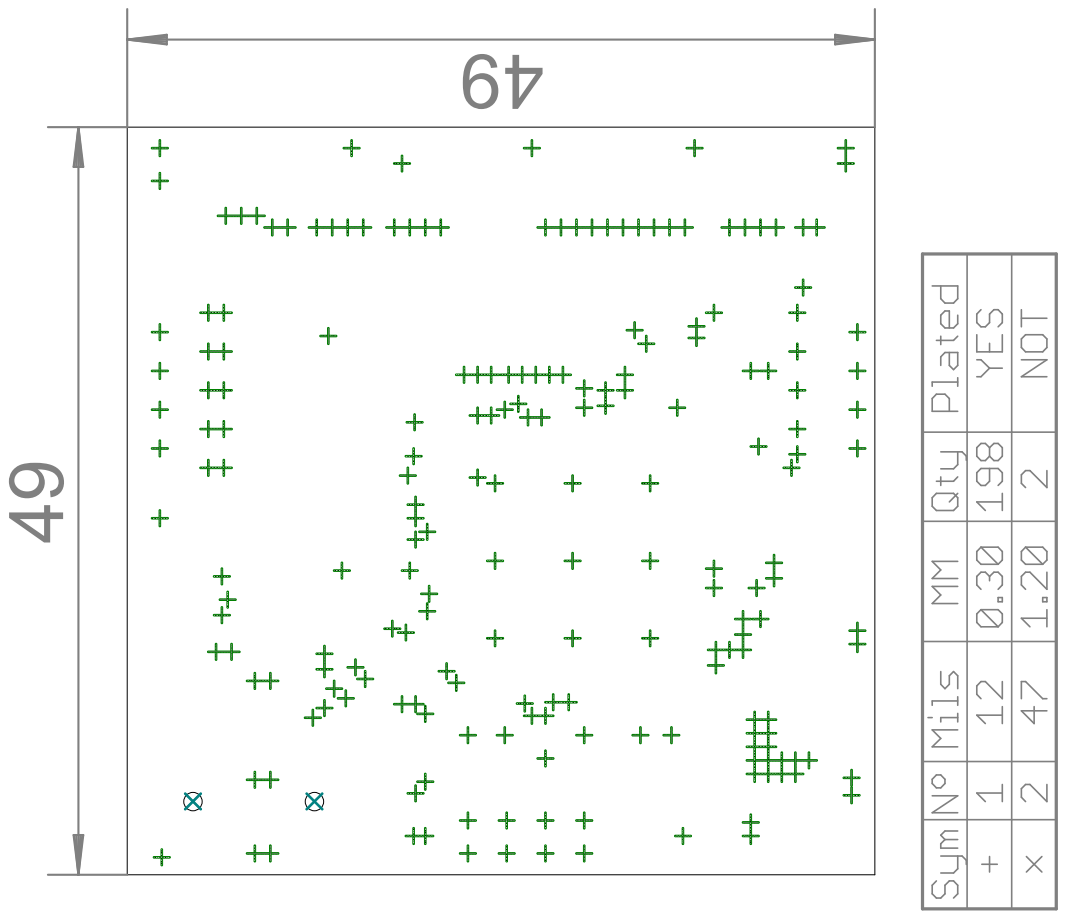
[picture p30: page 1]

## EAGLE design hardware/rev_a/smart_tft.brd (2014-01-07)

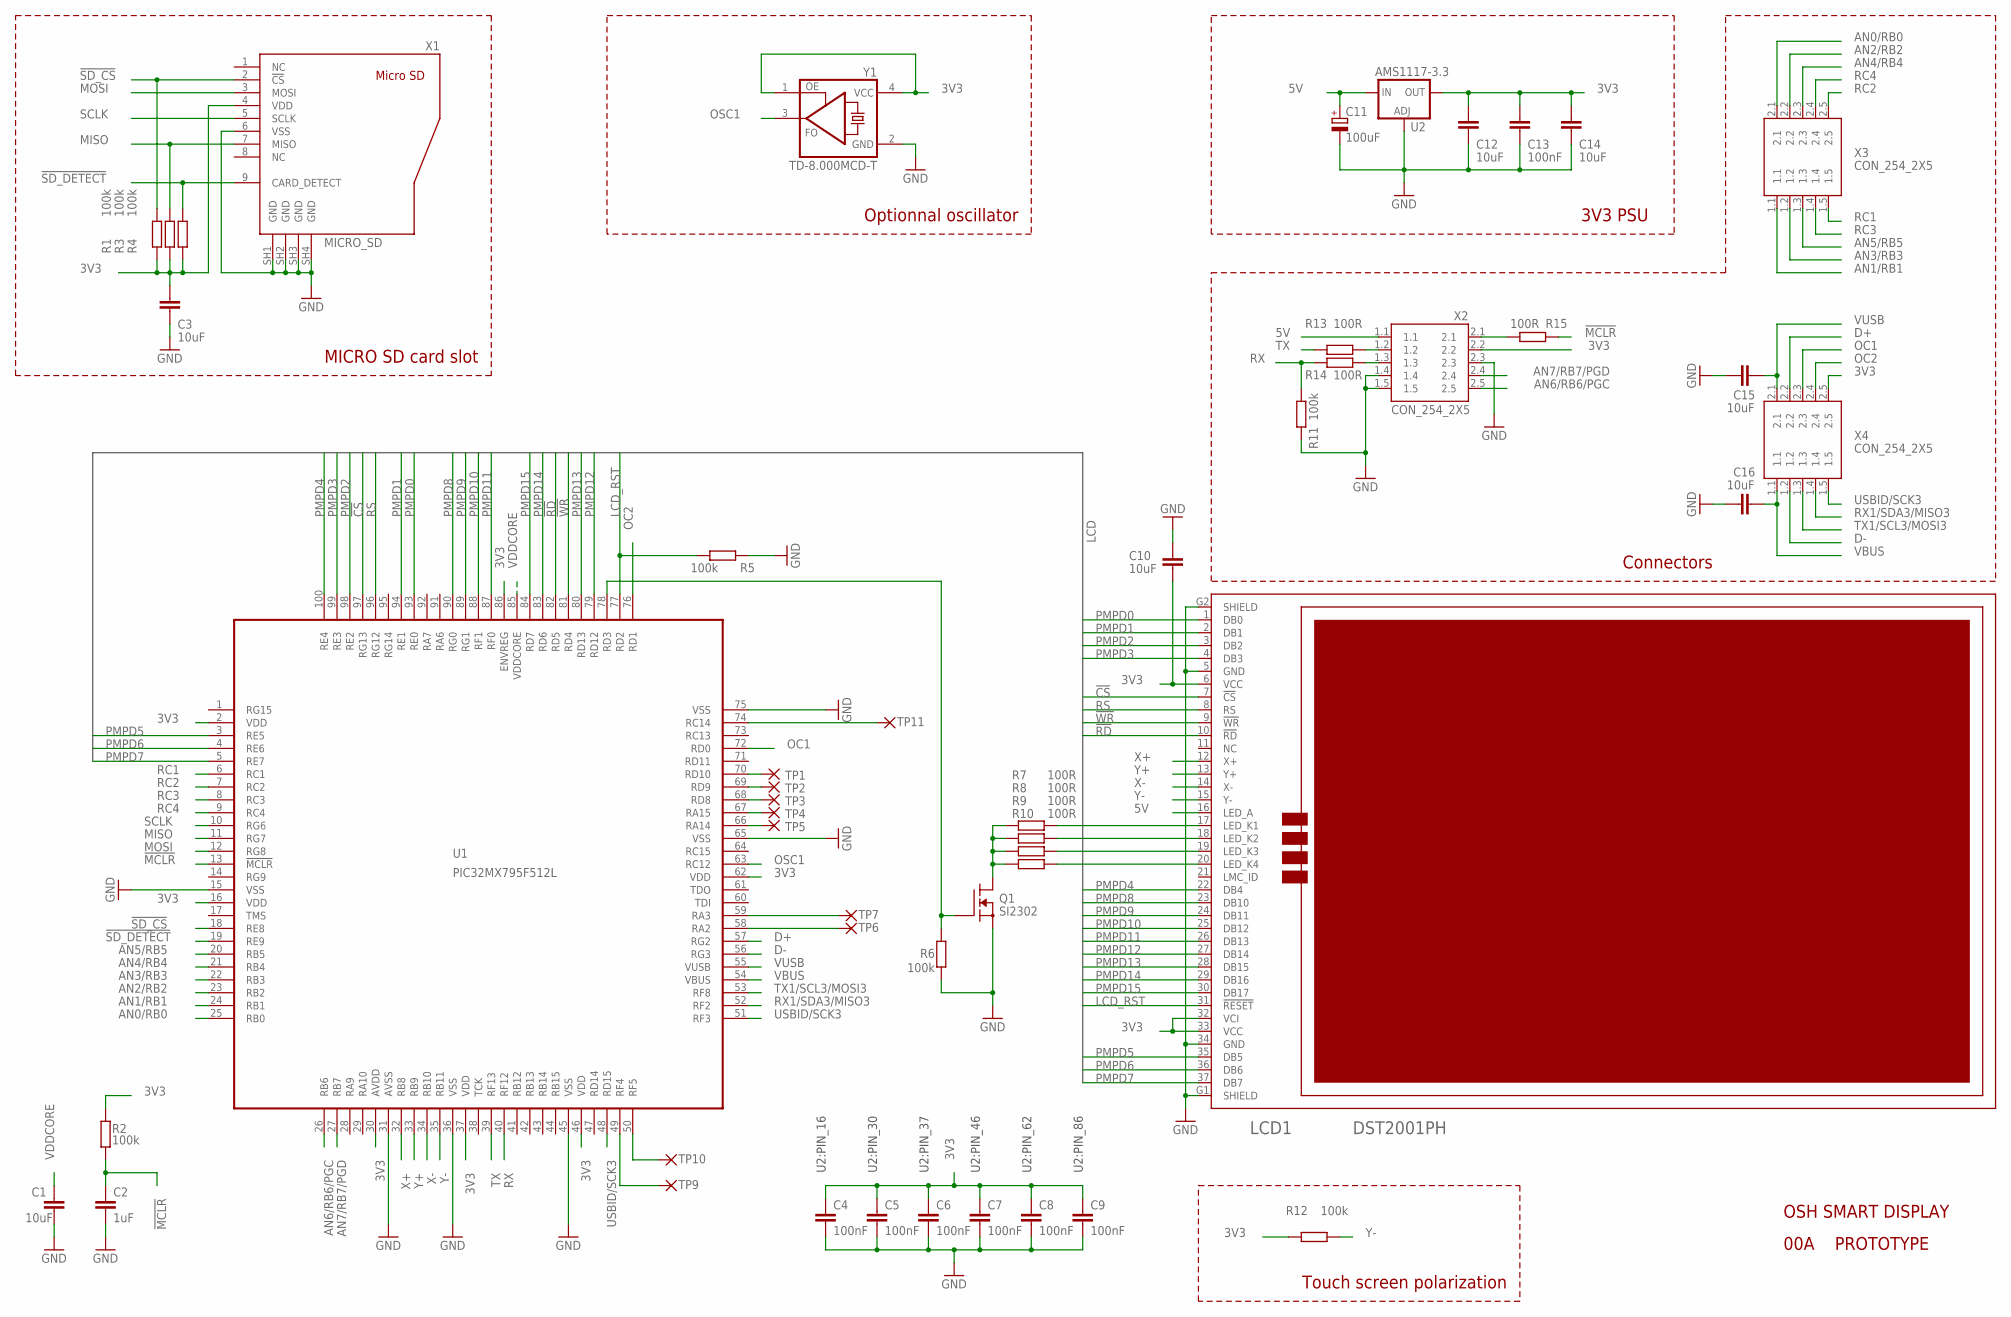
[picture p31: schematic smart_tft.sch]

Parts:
C1, C3, C10, C12, C14, C15, C16: 10uF; C0805
C2: 1uF; C0603
C4, C5, C6, C7, C8, C9, C13: 100nF; C0603
C11: 100uF; SMC_D
LCD1: DST2001PH
Q1: SI2302; SOT23-BEC
R1, R2, R3, R4, R5, R6, R11, R12: 100k; R0603
R7, R8, R9, R10, R13, R14, R15: 100R; R0603
TP1, TP2, TP3, TP4, TP5, TP6, TP7, TP9, TP10, TP11: 1.27R
U1: PIC32MX795F512L; TQFP100-14X14
U2: AMS1117-3.3; SOT223
X1: MICRO_SD; SD_MICRO
X2, X3, X4: CON_254_2X5; 2X5_CMS
Y1: TD-8.000MCD-T; ASF

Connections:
3V3: C3.1, C4.1, C5.1, C6.1, C7.1, C8.1, C9.1, C10.2, C12.1, C13.1, C14.1, LCD1.6 (VCC), LCD1.32 (VCI), LCD1.33 (VCC), R1.1, R2.2, R3.2, R4.2, R12.2, U1.2 (VDD), U1.16 (VDD), U1.30 (AVDD), U1.37 (VDD), U1.46 (VDD), U1.62 (VDD), U1.86 (ENVREG), U2.4 (OUT), X1.4 (VDD), X2.2.2, X4.2.5, Y1.1 (OE), Y1.4 (VCC)
5V: C11.+, LCD1.16 (LED_A), U2.3 (IN), X2.1.1
!CS: LCD1.7 (!CS), U1.97 (RG13)
!MCLR: C2.1, R2.1, R15.1, U1.13 (!MCLR)
!RD: LCD1.10 (!RD), U1.82 (RD5)
!SD_CS: R1.2, U1.18 (RE8), X1.2 (!CS)
!SD_DETECT: R4.1, U1.19 (RE9), X1.9 (CARD_DETECT)
!WR: LCD1.9 (!WR), U1.81 (RD4)
AN0/RB0: U1.25 (RB0), X3.2.1
AN1/RB1: U1.24 (RB1), X3.1.1
AN2/RB2: U1.23 (RB2), X3.2.2
AN3/RB3: U1.22 (RB3), X3.1.2
AN4/RB4: U1.21 (RB4), X3.2.3
AN5/RB5: U1.20 (RB5), X3.1.3
AN6/RB6/PGC: U1.26 (RB6), X2.2.5
AN7/RB7/PGD: U1.27 (RB7), X2.2.4
D+: U1.57 (RG2), X4.2.2
D-: U1.56 (RG3), X4.1.2
GND: C1.1, C2.2, C3.2, C4.2, C5.2, C6.2, C7.2, C8.2, C9.2, C10.1, C11.-, C12.2, C13.2, C14.2, C15.2, C16.2, LCD1.5 (GND), LCD1.34 (GND), LCD1.G1 (SHIELD), LCD1.G2 (SHIELD), Q1.E (S), R5.1, R6.1, R11.1, U1.15 (VSS), U1.31 (AVSS), U1.36 (VSS), U1.45 (VSS), U1.65 (VSS), U1.75 (VSS), U2.1 (ADJ), X1.6 (VSS), X1.SH1 (GND), X1.SH2 (GND), X1.SH3 (GND), X1.SH4 (GND), X2.1.4, X2.1.5, X2.2.3, Y1.2 (GND)
LCD_RST: LCD1.31 (!RESET), R5.2, U1.77 (RD2)
MISO: R3.1, U1.11 (RG7), X1.7 (MISO)
MOSI: U1.12 (RG8), X1.3 (MOSI)
unnamed: TP6.P$1, U1.58 (RA2)
unnamed: Q1.C (D), R7.1, R8.1, R9.1, R10.1
unnamed: Q1.B (G), R6.2, U1.78 (RD3)
unnamed: R13.2, X2.1.2
unnamed: R14.2, X2.1.3
unnamed: TP7.P$1, U1.59 (RA3)
unnamed: TP5.P$1, U1.66 (RA14)
unnamed: TP4.P$1, U1.67 (RA15)
unnamed: LCD1.20 (LED_K4), R10.2
unnamed: LCD1.19 (LED_K3), R9.2
unnamed: LCD1.18 (LED_K2), R8.2
unnamed: LCD1.17 (LED_K1), R7.2
unnamed: TP3.P$1, U1.68 (RD8)
unnamed: TP2.P$1, U1.69 (RD9)
unnamed: TP1.P$1, U1.70 (RD10)
unnamed: TP9.P$1, U1.49 (RF4)
unnamed: TP10.P$1, U1.50 (RF5)
unnamed: TP11.P$1, U1.74 (RC14)
unnamed: R15.2, X2.2.1
OC1: U1.72 (RD0), X4.2.3
OC2: U1.76 (RD1), X4.2.4
OSC1: U1.63 (RC12), Y1.3 (FO)
PMPD0: LCD1.1 (DB0), U1.93 (RE0)
PMPD1: LCD1.2 (DB1), U1.94 (RE1)
PMPD2: LCD1.3 (DB2), U1.98 (RE2)
PMPD3: LCD1.4 (DB3), U1.99 (RE3)
PMPD4: LCD1.22 (DB4), U1.100 (RE4)
PMPD5: LCD1.35 (DB5), U1.3 (RE5)
PMPD6: LCD1.36 (DB6), U1.4 (RE6)
PMPD7: LCD1.37 (DB7), U1.5 (RE7)
PMPD8: LCD1.23 (DB10), U1.90 (RG0)
PMPD9: LCD1.24 (DB11), U1.89 (RG1)
PMPD10: LCD1.25 (DB12), U1.88 (RF1)
PMPD11: LCD1.26 (DB13), U1.87 (RF0)
PMPD12: LCD1.27 (DB14), U1.79 (RD12)
PMPD13: LCD1.28 (DB15), U1.80 (RD13)
PMPD14: LCD1.29 (DB16), U1.83 (RD6)
PMPD15: LCD1.30 (DB17), U1.84 (RD7)
RC1: U1.6 (RC1), X3.1.5
RC2: U1.7 (RC2), X3.2.5
RC3: U1.8 (RC3), X3.1.4
RC4: U1.9 (RC4), X3.2.4
RS: LCD1.8 (RS), U1.96 (RG12)
RX: R11.2, R14.1, U1.40 (RF12)
RX1/SDA3/MISO3: U1.52 (RF2), X4.1.4
SCLK: U1.10 (RG6), X1.5 (SCLK)
TX: R13.1, U1.39 (RF13)
TX1/SCL3/MOSI3: U1.53 (RF8), X4.1.3
USBID/SCK3: U1.48 (RD15), U1.51 (RF3), X4.1.5
VBUS: C16.1, U1.54 (VBUS), X4.1.1
VDDCORE: C1.2, U1.85 (VDDCORE)
VUSB: C15.1, U1.55 (VUSB), X4.2.1
X+: LCD1.12 (X+), U1.32 (RB8)
X-: LCD1.14 (X-), U1.34 (RB10)
Y+: LCD1.13 (Y+), U1.33 (RB9)
Y-: LCD1.15 (Y-), R12.1, U1.35 (RB11)

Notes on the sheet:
PROTOTYPE
00A
U2:PIN_16
U2:PIN_37
U2:PIN_46
U2:PIN_62
U2:PIN_86
U2:PIN_30
Touch screen polarization
MICRO SD card slot
Optionnal oscillator
3V3 PSU
Connectors
OSH SMART DISPLAY

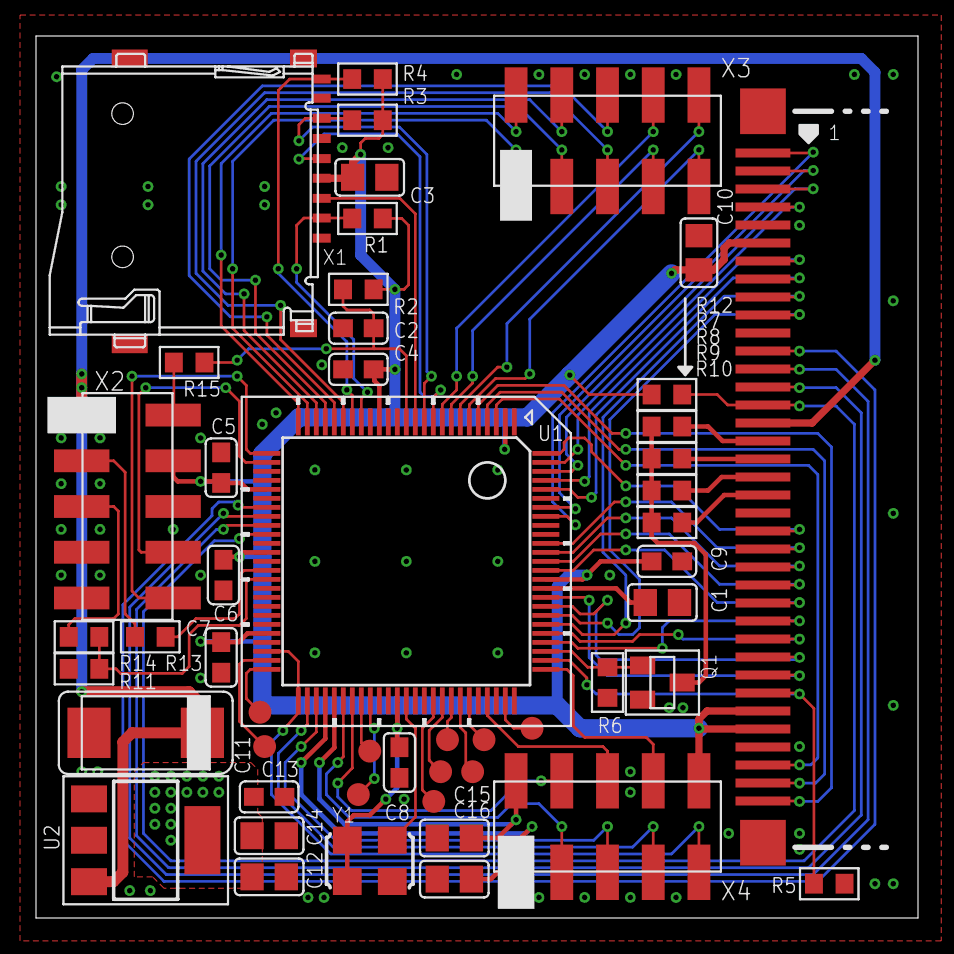
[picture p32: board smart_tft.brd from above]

Board: 2 copper layers, 49.0 x 49.0 mm, 50 parts (0 on the bottom side), 78 nets.

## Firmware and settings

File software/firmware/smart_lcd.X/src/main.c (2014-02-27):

/**
 * @file main.c
 * @brief SMART TFT software entry point
 * @author Duboisset Philippe
 * @version 0.3b
 * @date (yyyy-mm-dd) 2013-11-01
 *
 * Copyright (C) <2013>  Duboisset Philippe <duboisset.philippe@gmail.com>
 *
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
 * You should have received a copy of the GNU General Public License
 * along with this program.  If not, see <http://www.gnu.org/licenses/>.
 */

#include "main.h"
#include "uc.h"
#include "ticks.h"
#include "delay.h"

#include "ILI9320.h"
#include "backlight.h"
#include "touchscreen.h"

#include "p2d.h"
#include "gui.h"
#include "setup.h"

#include "rtc.h"
#include "diskio.h"
#include "ff.h"


#if DISP_ORIENTATION == 90 || DISP_ORIENTATION == 270
  #warning "setup menu & demo are not designed (yet) to support such orientation"
#endif


/**
 * global variable
 */
void (*pCurrentTask) (void) = NULL;


/**
 * local variable
 */
static FATFS Fatfs;


/**
 * @function main
 * @brief entry point
 * @param none
 * @return dummy
 */
int32_t main(void) {

  timer_t tmInit;

  UcInit();       /*uc init; shall be the first one*/
  TicksInit();    /*software clock init*/
  LCD_Init();     /*start the ILI932X*/

  /* start a timer; backlight will be turned on once this timer will elapse
   * -> this avoids a white flash*/
  tmInit = GetTimeout(120);

  P2D_Init();
  GUI_Init();
  TouchScreenCalib(NULL);
  TouchScreenEnable();

  /*mount the file system*/
  disk_initialize(0);
  f_mount(0, &Fatfs);

  /* wait the 120ms timeout */
  while(IsTimerElapsed(tmInit) == false) DelayMs(1);
  BacklightInit();

  /*set the main task*/
  pCurrentTask = &SetupTask;

  /*main loop*/
  while(1) {

    /*execute the main task, if any*/
    if(pCurrentTask != NULL) pCurrentTask();

    /*GUI task*/
    GUI_DrawObjects();
    GUI_DBG_Task();

    /*software RTC task*/
    RtcTask();

    /*CPU limiter; reduces the power consumption*/
    DelayMs(1);
  }

  /*never arrive here*/
  return -1;
}

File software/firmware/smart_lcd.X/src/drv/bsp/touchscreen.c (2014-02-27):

/**
 * @file touchscreen.c
 * @brief resistive touchscreen driver
 * @author Duboisset Philippe
 * @version 0.4b
 * @date (yyyy-mm-dd)
 * 2013-07-13 initial version
 * 2013-09-22 modification of TouchScreenCalib(NULL)
 * 2013-09-26 modification to avoid the parasit capacitance error
 * 2014-02-20 support of display orientation (0, 90, 180, 270°)
 *
 * Copyright (C) <2013>  Duboisset Philippe <duboisset.philippe@gmail.com>
 *
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
 * You should have received a copy of the GNU General Public License
 * along with this program.  If not, see <http://www.gnu.org/licenses/>.
 */

#include "touchscreen.h"
#include "adc.h"
#include "gpio.h"
#include "sem.h"
#include "tmr.h"

#define X_P_PORT  B
#define X_P_PIN   8
#define X_N_PORT  B
#define X_N_PIN   10
#define Y_P_PORT  B
#define Y_P_PIN   9
#define Y_N_PORT  B
#define Y_N_PIN   11

#define NB_SAMPLE         6   /*number of sample for filtering; shall be >= 2 to make the filter effective*/
#define TOUCH_TRIG        100 /*touch detection threeshold; empiric value*/
#define SAMPLE_TOLERANCE  12  /*tolerance between successive samples; empiric value*/

/*
 * Local functions
 */
static void FlushSamples(void);
static uint16_t Delta(uint16_t a, uint16_t b);
static uint16_t Average(volatile uint16_t *p, uint8_t nbSample);
static void TouchScreenIsr(void);

/*
 * Static variable used by the touchscreen ISR
 */
static volatile uint16_t xRead[NB_SAMPLE], yRead[NB_SAMPLE];
static volatile uint8_t state, posSample;
static volatile sem_t sem;
static volatile bool bTouch;

/*
 * Static variable used for calibration
 */
static float cx = 0.0f;
static float ox = 0.0f;
static float cy = 0.0f;
static float oy = 0.0f;



/**
 * @function TouchScreenEnable
 * @brief turn ON the touchscreen; overwrite ADC & TMR3 configuration
 * @param none
 * @return none
 */
void TouchScreenEnable(void) {

  GPIO_SetPin(Y_N_PORT, Y_N_PIN, 0);      /*preconfigured for 0V  output*/
  GPIO_SetPin(Y_P_PORT, Y_P_PIN, 1);      /*preconfigured for 3V3 output*/
  GPIO_SetPin(X_N_PORT, X_N_PIN, 0);      /*preconfigured for 0V  output*/
  GPIO_SetPin(X_P_PORT, X_P_PIN, 1);      /*preconfigured for 3V3 output*/
  GPIO_SetPinMode(Y_P_PIN, GPIO_ANALOG);  /*Y_P_PIN as analog input or digital output*/
  GPIO_SetPinMode(X_P_PIN, GPIO_ANALOG);  /*X_P_PIN as analog input or digital output*/

  ADC_Init();

  /*variable init.*/
  FlushSamples();
  state = 0;
  bTouch = false;
  sem = SEM_UNLOCKED;

  /*set up & run touchscreen ISR @ 4kHz*/
  TmrSetFrequency(TMR_3, 4000);
  TmrSetCallback(TMR_3, TouchScreenIsr);
  TmrLaunch(TMR_3);
}


/**
 * @function TouchScreenDisable
 * @brief turn OFF the touchscreen
 * @param none
 * @return none
 */
void TouchScreenDisable(void) {

  /*kill touchscreen ISR*/
  TmrStop(TMR_3);

  /*consider touchscreen as released if disabled*/
  bTouch = false;

  /*release plate polarization, if any*/
  GPIO_SetPinDirection(X_N_PORT, X_N_PIN, GPIO_PIN_INPUT);
  GPIO_SetPinDirection(X_P_PORT, X_P_PIN, GPIO_PIN_INPUT);
  GPIO_SetPinDirection(Y_N_PORT, Y_N_PIN, GPIO_PIN_INPUT);
  GPIO_SetPinDirection(Y_P_PORT, Y_P_PIN, GPIO_PIN_INPUT);
}


/**
 * @function TouchScreenIsPressed
 * @brief return the touch screen state
 * @param none
 * @return bool: true if touched, false otherwise
 */
bool TouchScreenIsPressed(void) {
  return bTouch;
}


/**
 * @function TouchScreenReadRaw
 * @brief read the touchscreen filtered raw data
 * @param uint16_t *x, *y: x & y coordinate, in range[0 - (ADC_MAX_VALUE-1)]; ADC_RAW_ERR if touchscreen released
 * @return none
 */
void TouchScreenReadRaw(uint16_t *x, uint16_t *y) {

  static uint16_t oldX = ADC_MAX_VALUE, oldY = ADC_MAX_VALUE;
  uint16_t avgX, avgY, cnt;
  bool bBounce = false;

  if(x != NULL && y != NULL) {

    /*lock touchscreen ISR*/
    SemLock(sem);

    /*check if the touchscreen is actually pressed*/
    if(bTouch == true) {

      /*compute average x & y*/
      avgX = Average(xRead, NB_SAMPLE);
      avgY = Average(yRead, NB_SAMPLE);

      /*check if a sample is not too far (possible bounces issue)*/
      for(cnt = 0; bBounce == false && cnt < NB_SAMPLE; cnt++) {
        if(Delta(avgX, xRead[cnt]) > SAMPLE_TOLERANCE) bBounce = true;
        if(Delta(avgY, yRead[cnt]) > SAMPLE_TOLERANCE) bBounce = true;
      }
      /*if no bounce issue, return the new point*/
      if(bBounce == false) {
        *x = avgX;
        *y = avgY;
      }
      /*if bounce issue and screen still pressed, return the previous point*/
      else {
        *x = oldX;
        *y = oldY;
      }
    }
    else {
      *x = ADC_RAW_ERR;
      *y = ADC_RAW_ERR;
    }

    /*always save current result*/
    oldX = *x;
    oldY = *y;

    /*release ISR*/
    SemUnlock(sem);
  }
}


/**
 * @function TouchScreenRead
 * @brief read the touchscreen filtered coordinate (relative to screen dimension)
 * @param coord_t *x: range[0 - LCD_GetWidth()-1]; -1 if touchscreen released
 * @param coord_t *y: range[0 - LCD_GetHeight()-1]; -1 if touchscreen released
 * @return none
 */
void TouchScreenRead(coord_t *x, coord_t *y) {

  uint16_t xt, yt;

  if(x != NULL && y != NULL) {

    /*read touchscreen raw*/
    TouchScreenReadRaw(&xt, &yt);

    /*touchscreen pressed*/
    if(xt != ADC_MAX_VALUE && yt != ADC_MAX_VALUE) {

      /*convert x & y*/
      *x = (coord_t) (cx*xt + ox);
      *y = (coord_t) (cy*yt + oy);

      /*check overlap*/
      if(*x < 0) *x = 0;
      else if(*x >= LCD_GetWidth()) *x = LCD_GetWidth() - 1;
      if(*y < 0) *y = 0;
      else if(*y >= LCD_GetHeight()) *y = LCD_GetHeight() - 1;
    }
    /*touchscreen released*/
    else {
      *x = -1;
      *y = -1;
    }
  }
}


/**
 * @function TouchScreenCalib
 * @brief set calibration parameters, based on 2 points
 * @param const touch_calib_st *z: calibration points (touchscreen data & relative coordinates)
 * @return int8_t: 0=success, -1=error (invalid parameters leading to /0 )
 */
int8_t TouchScreenCalib(const touch_calib_st *z) {

  int8_t res = -1;
  int16_t denom;

  if(z != NULL) {

    do {

      cx = z->xd1 - z->xd2;
      denom = z->xt1 - z->xt2;
      if(denom == 0) break;
      else cx /= denom;

      ox = z->xt1 * z->xd2 - z->xt2 * z->xd1;
      denom = z->xt1 - z->xt2;
      if(denom == 0) break;
      else ox /= denom;

      cy = z->yd1 - z->yd2;
      denom = z->yt1 - z->yt2;
      if(denom == 0) break;
      else cy /= denom;

      oy = z->yt1 * z->yd2 - z->yt2 * z->yd1;
      denom = z->yt1 - z->yt2;
      if(denom == 0) break;
      else oy /= denom;

      res = 0;

    } while(0);
  }

  /*in case of errors, set coeff to default values*/
  if(res < 0) {
    cx = 0.3897f;
    ox = -31.52f;
    cy = -0.3174f;
    oy = 277.8f;
  }

  return res;
}
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
